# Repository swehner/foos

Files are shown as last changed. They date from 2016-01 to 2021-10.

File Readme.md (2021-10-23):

# Foosball slow motion instant replay

Ever wanted to relive your best foosball shots? Now you can with this project!
Featuring:
 * Automatic goal detection & score-keeping
 * Automatic instant replay (2x slow motion) of the last goal
 * Upload replays to Youtube
 * HipChat integration to send Youtube URLs and report game progress
 * Integration with a league system

See a video of it in action:

Instant replay video (https://www.youtube.com/watch?v=BXMhitiaXEE)

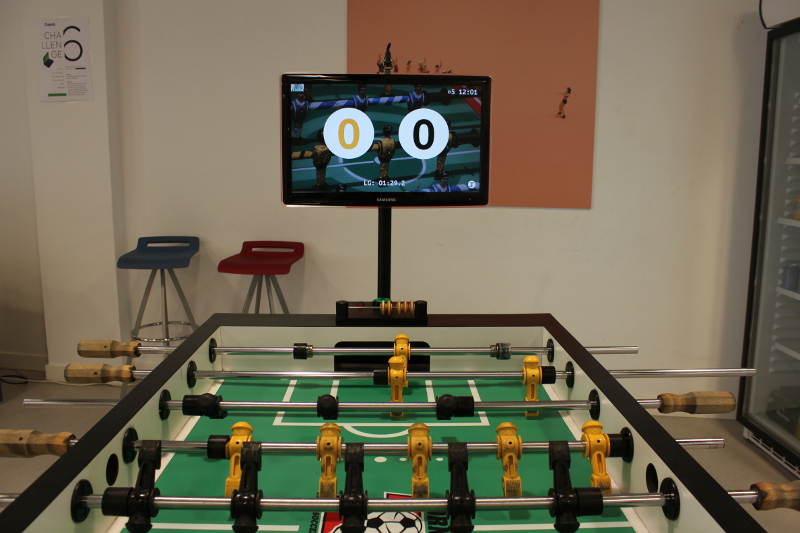
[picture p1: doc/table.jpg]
table


To build it you'll need
 * A foosball table ;)
 * A TV
 * A Raspberry Pi (2 or 3) to run the UI - **Note - the Raspberry Pi4 is not supported**
 * The Raspberry Pi camera module to record video
 * Some electronic components for the goal detection (and maybe an Arduino)

You can find more info on how to build its components in the [doc folder](doc/HWSetup.md)

Take a closer look at the UI and the different game modes in the [ui folder](doc/ui/ui.md)

## Installation

To install it on a RaspberryPi please follow the [installation guide](doc/Installation.md)

## Running on a normal PC

When running in X11 it's often useful to change the window size changing the scaling factor (-s 3 runs at 1/3 of the size)
```
python3 foos.py -s 3
```

If you want to use a keyboard on the Raspberry PI you can enable the io_evdev_keyboard plugin.
This will read directly from the evdev input device (make sure pi user is in the input group and has access to /dev/input/*)
Remember this will only work on physical keyboards attached to the PI - not if you're pressing keys in a ssh session!

Keys in X11 and Raspberry PI:
 * Increment goal counter: `q, KP7, e, KP9`
 * Decrement goal counter: `z, KP1, c, KP3`
 * Ok: `s, KP5`
 * Simulate goal: `a, KP4, d, KP6`
 * Exit: `.`

## Troubleshooting

Please check the [Troubleshooting](doc/Troubleshooting.md) section for some common issues.

## Acknowledgments

Team:
 * Jesús Bravo
 * Daniel Pañeda
 * Stefan Wehner

Big thanks to:
 * [Tuenti](http://www.tuenti.com), where this project started as a HackMeUp
 * Laura Andina for the UI design
 * [Adam Bartha](https://github.com/bartha-adam) for the Pi-only version
 * [Steve Brockman](https://github.com/sbrockman) for the Arduino micro version

Made with Pi3d

Pi3d logo (https://pi3d.github.io/)

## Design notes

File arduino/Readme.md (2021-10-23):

# Arduino Options

The [arduino](.) folder orgranizes the arduino designs into directories based on different Model/Configurations for supported Arduinos.  

The table below list the directories with their corresponding arduino model sketches.

Directory | Model | Description | Diagram |
| --- | ----------- | --------------------------- | ---- |
| foos_arduino | Nano | Original IR/NPN Design utilizing diagram | [schematic](../doc/schematics/foos_arduino_schem.png) |
| foos_arduino_micro | Micro | Original IR/NPN Design using a Micro instead of a Nano | [schematic](../doc/schematics/foos_arduino_micro_schem.png) |
| foos_arduino_micro_bb | Micro | Design utilizing Adafruit's Break Beam sensor | [schematic](../doc/schematics/micro_breakbeam_schem.png) |

Utilizing the [Adafruit breakbeam sensor](https://www.adafruit.com/product/2167), the use of the D9 (pwm) pin and NPN are eliminated.  Additionally, the D2/D3 pins have been freed up, incase we add support for an lcd1602/I2C, or lcd2004/I2C display.

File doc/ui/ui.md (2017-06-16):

# UI

Here's a quick look at the UI and the different game modes.

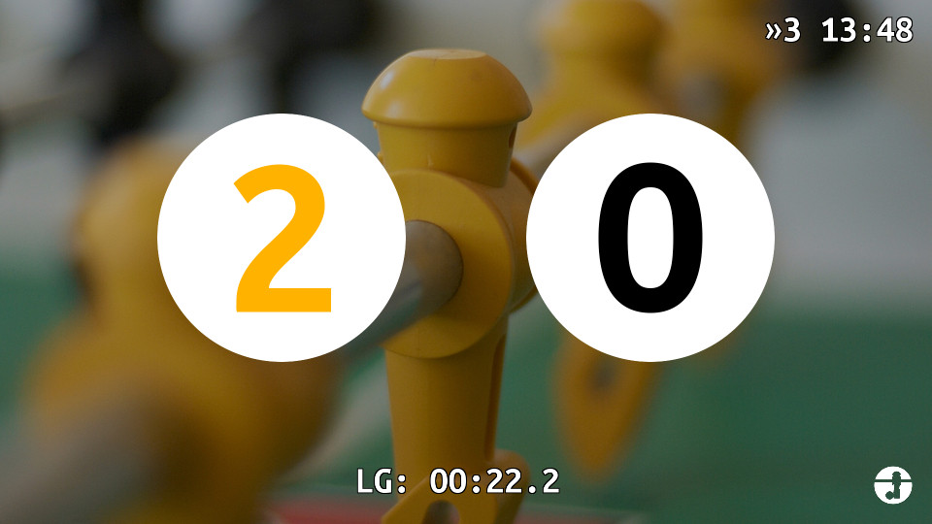
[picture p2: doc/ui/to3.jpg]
to3


## Basic game mode

In the basic game mode, the UI shows the scroe for both teams in the center, the current time in the upper right corner and the time elapsed since the last goal at the bottom.
The game can either be limited to a number of goals, which when reached displays the winning team and then resets to 0, or free, where counters simply roll over at 10.

## Menu

To change the game mode you can call up the menu (pressing the increment and decrement keys for a team at the same time, Q-Z or E-C on the keyboard)

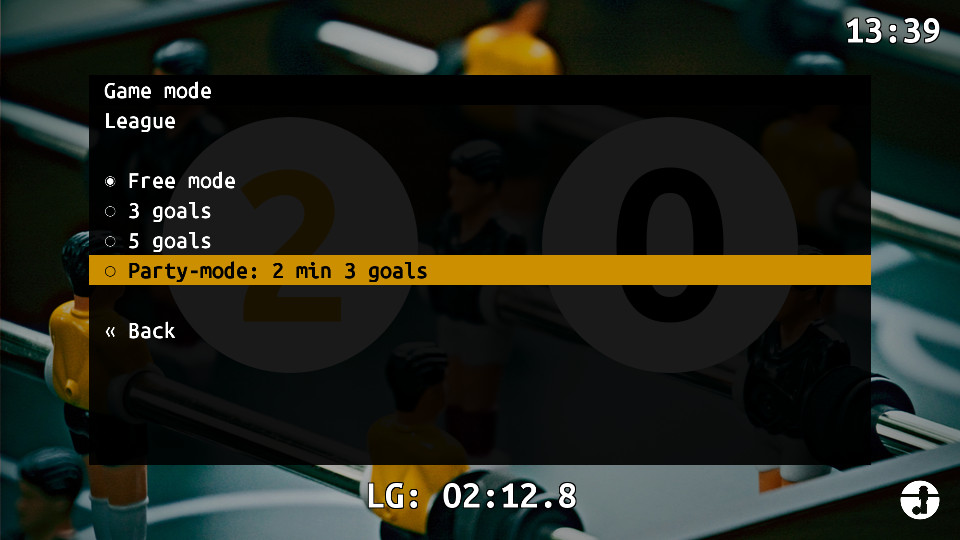
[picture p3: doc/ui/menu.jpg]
menu


Use the increment/decrement button to navigate and the replay button (S on the keyboard) to choose that menu item.

## Party mode

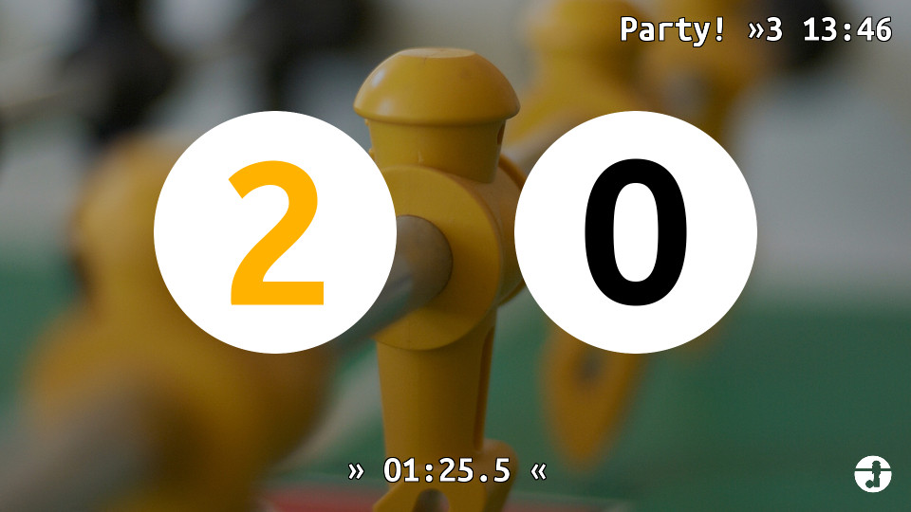
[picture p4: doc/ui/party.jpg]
party


The party mode is a game with a time limit - you can configure the winning score and the timeout in the configuration.
Party mode is indicated in the top right corner, when enabled.
The time since last goal indicator in the bottom is replaced by a countdown.
If a team wins before the time runs out, the game ends immediately. If the time runs out before, the leading time is declared winner, if no team is leading the game enters a sudden death round and the next score decides the game.
This mode is especially useful when a lot of players are playing to keep matches down to a shorter time allowing for more rotation.

## League mode

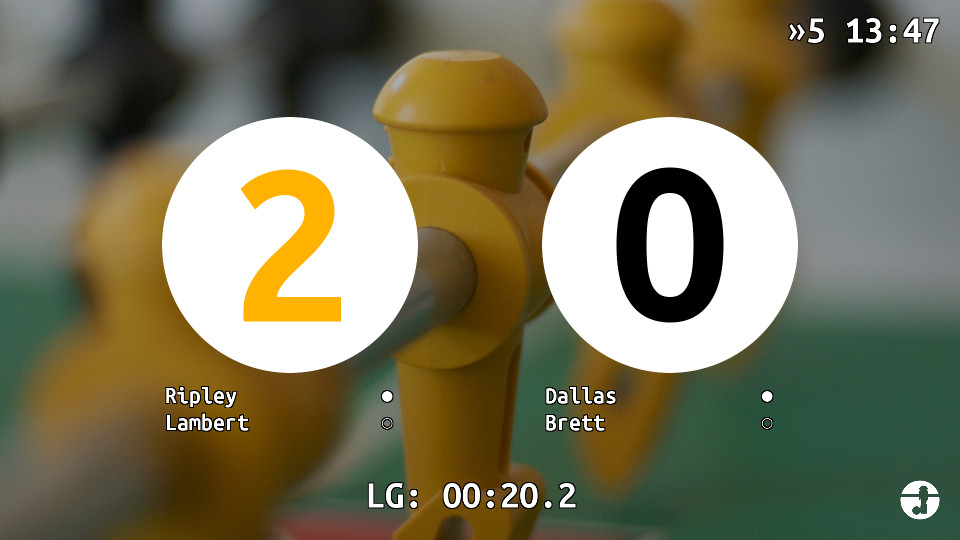
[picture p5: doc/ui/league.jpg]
league


The foosball game is integrated with a league system (https://github.com/netsuso/foos-tournament), it supports several leagues at the same time. Matches are assigned to groups of four people and will show up in the game menu.
Choose the game to play from the menu and you will start an official game. Each one consists of three matches with the players rotating so that all combination of pairs are played.
Team assignments are shown when a league game is started by showing the names of each player under the corresponding team's score counter.
After each match, a score counter is added to the player names showing how many matches the player has won/lost, and the player positions are changed.
As soon as the game ends, the results are sent to the league server, but before that official games can be aborted at any time from the menu.

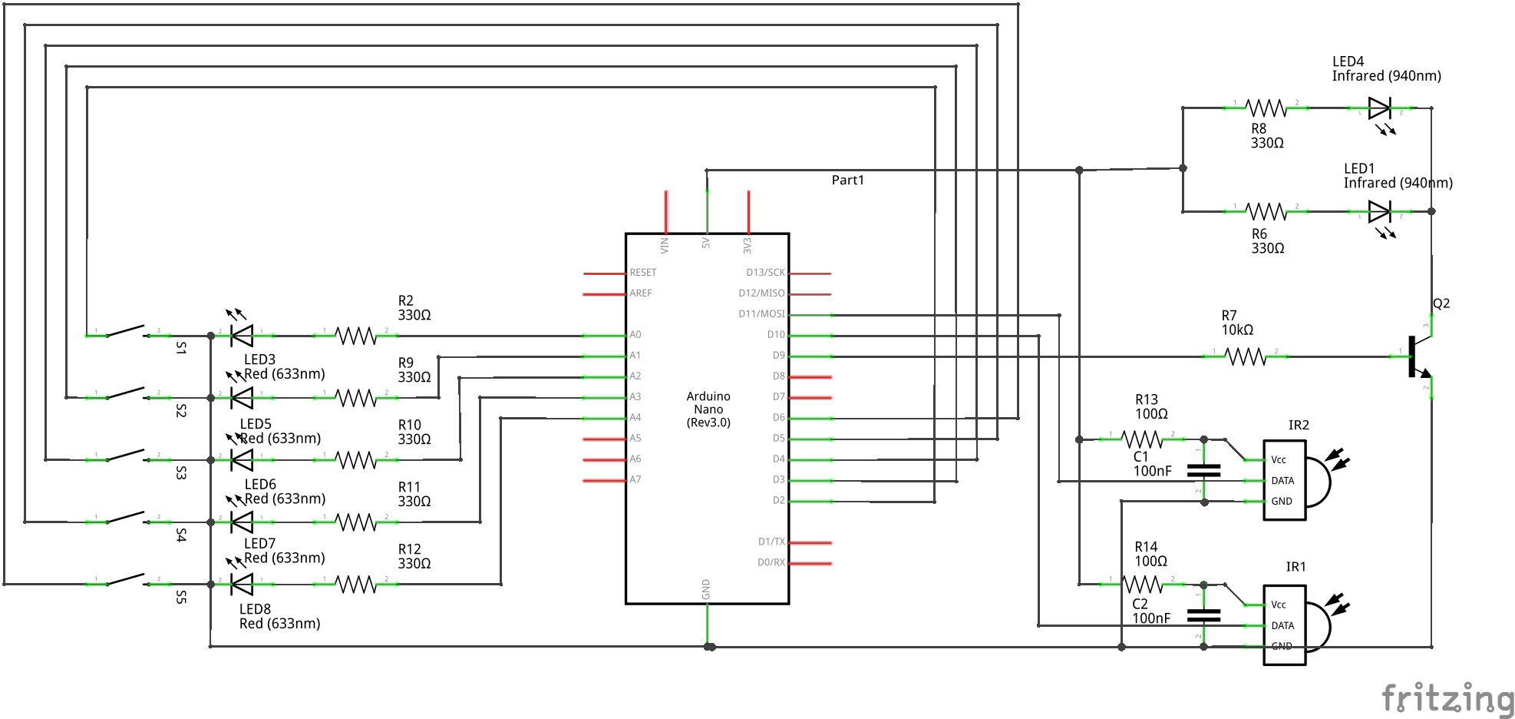
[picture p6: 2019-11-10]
doc/schematics/foos_arduino_schem.png

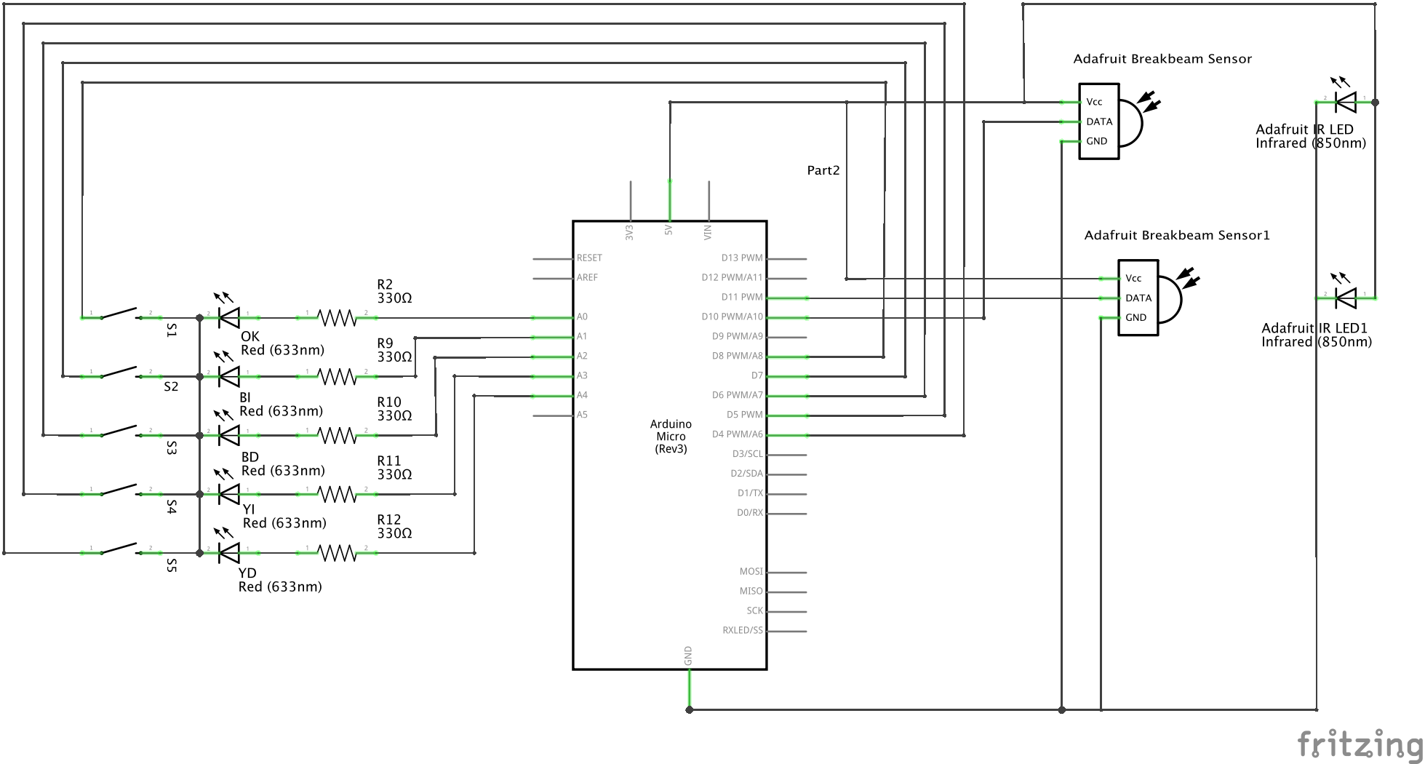
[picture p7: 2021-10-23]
doc/schematics/micro_breakbeam_schem.png

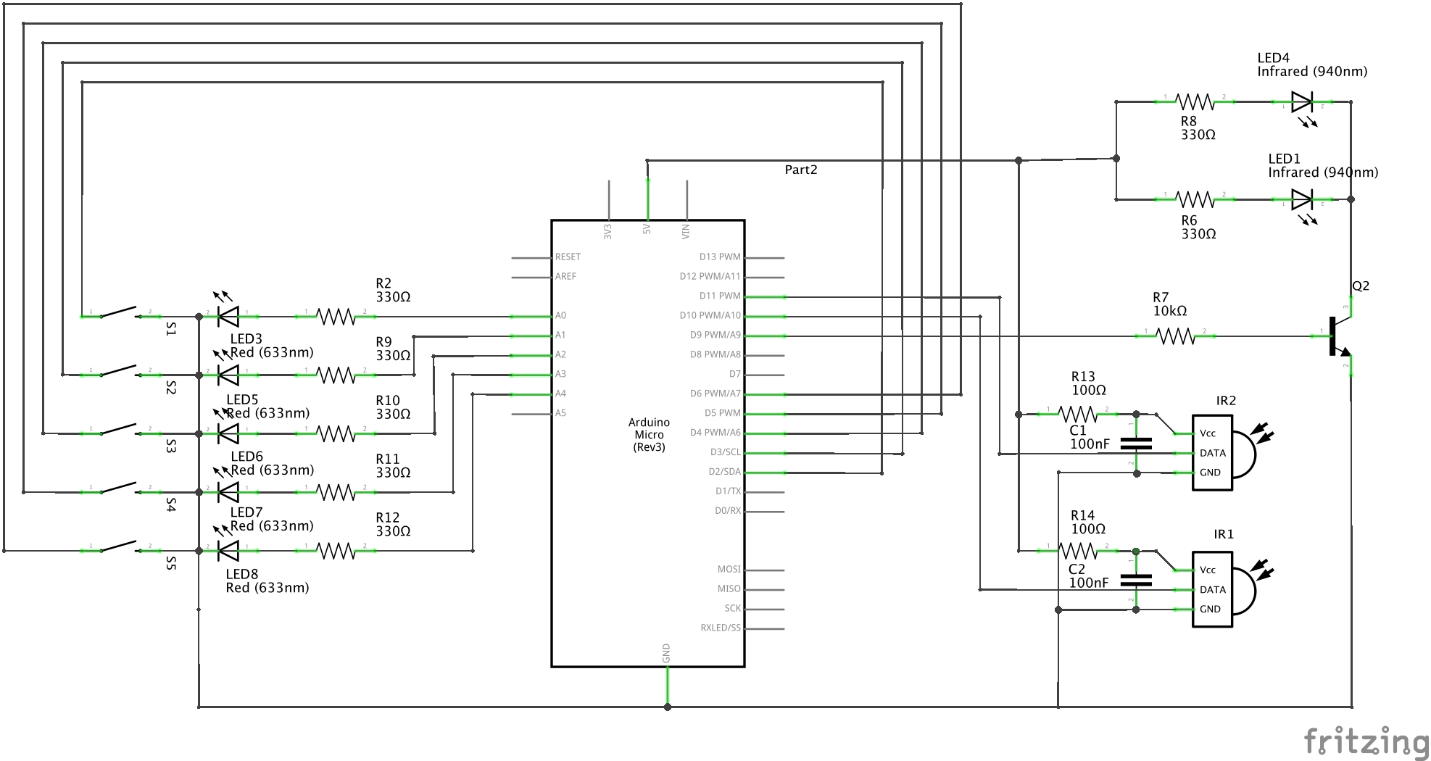
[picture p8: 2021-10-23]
doc/schematics/foos_arduino_micro_schem.png

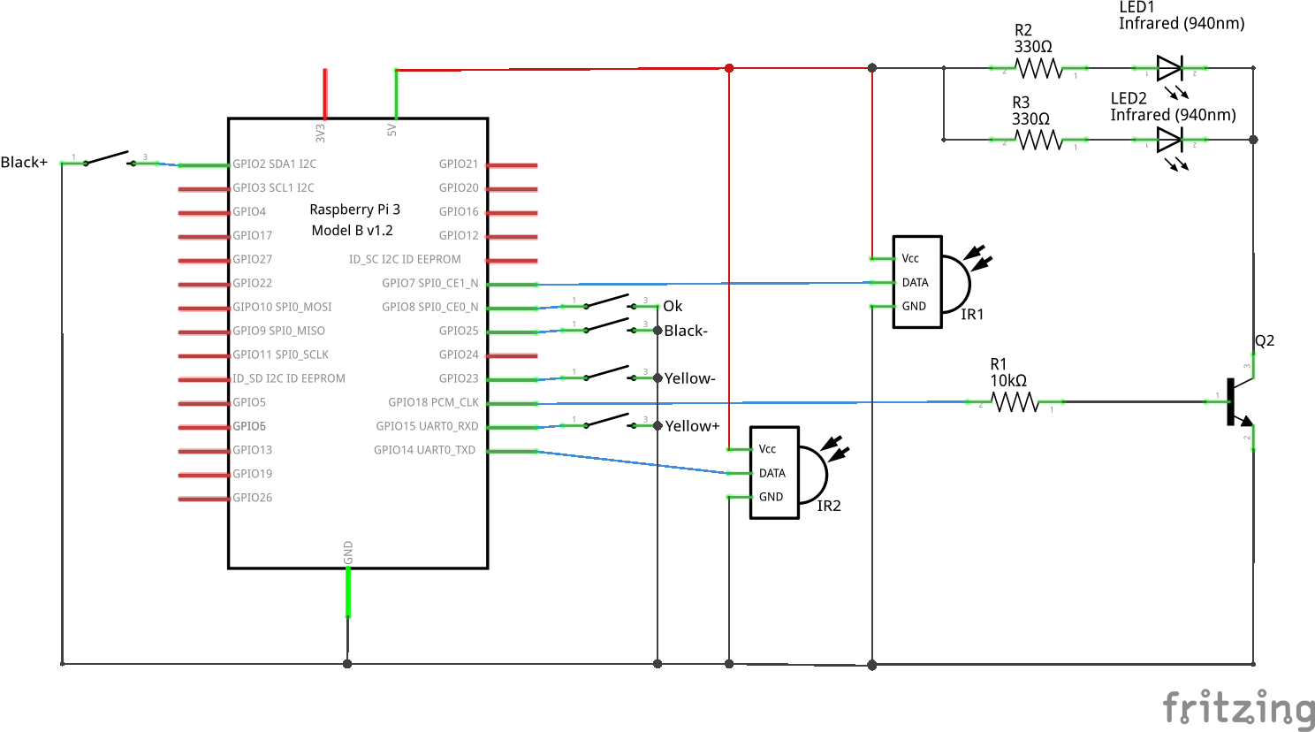
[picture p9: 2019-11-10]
doc/schematics/foos_RPi_only_schema.png

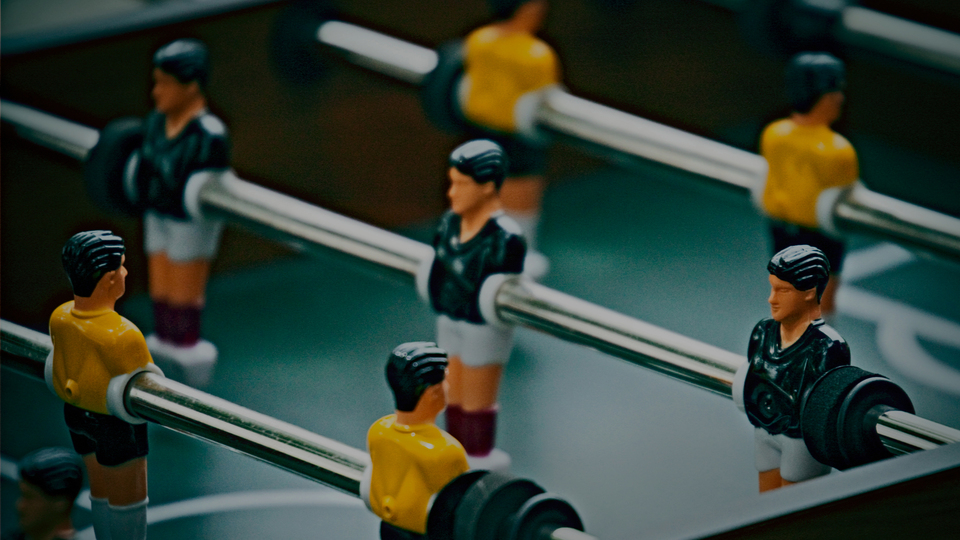
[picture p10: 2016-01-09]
img/bg/3925089065_cf3d9ea0ec_o.jpg

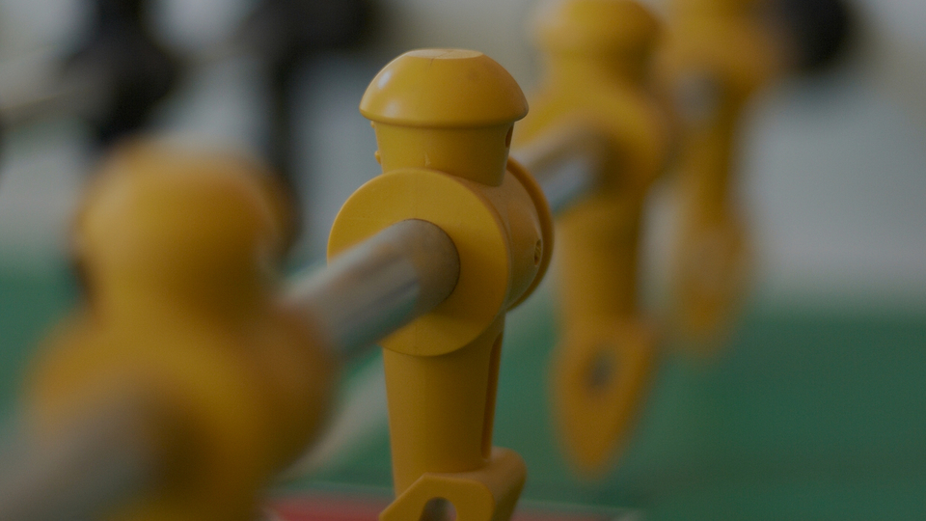
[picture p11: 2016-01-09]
img/bg/cc4.jpg

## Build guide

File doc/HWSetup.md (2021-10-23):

# Hardware Setup

These are the following hardware elements needed for the replay setup:
 * Raspberry Pi
 * Raspberry Pi camera module
 * Optional: Arduino (Nano) w/ push buttons and IR barrier
 * TV

table

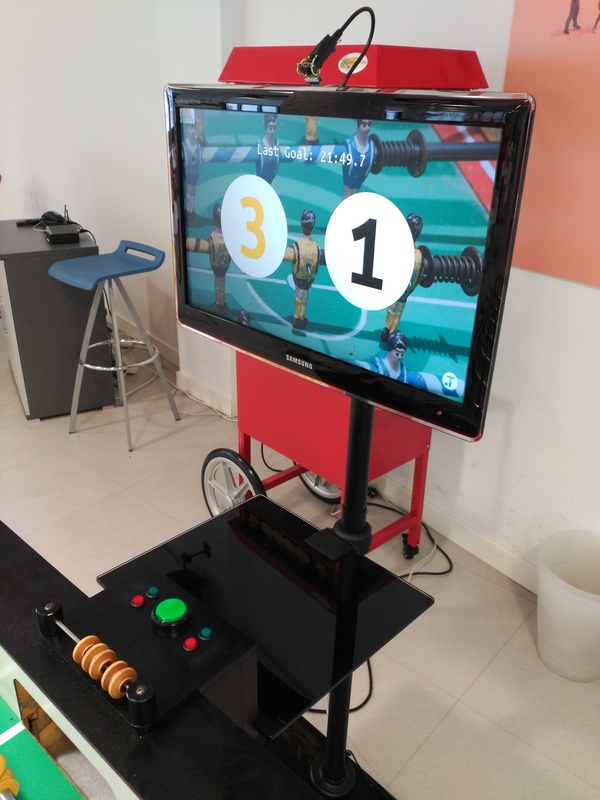
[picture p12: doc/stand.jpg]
stand


## Goal detection

We've chosen an IR barrier for the goal detection - using a regular IR LED together with the [TSSP58038](http://www.vishay.com/docs/82479/tssp58038.pdf) receiver module.
It is installed under the board, in the ball guide where the balls roll to the pick-up slot. We drilled holes on each side of the ramp and install the emitter on one side and the reciever on the other.
Due to the table's construction it's possible for balls coming in the black goal to run all the way up towards the yellow goal and actually going through the IR barrier. To avoid this there's a minimum time between goals that the GUI checks for.

IR barrier mounted undear each goal

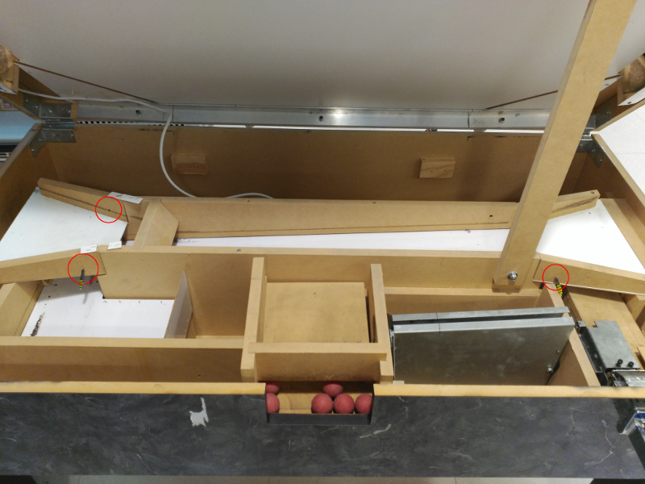
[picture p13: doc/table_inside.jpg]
Table inside overview


IR emitting LED

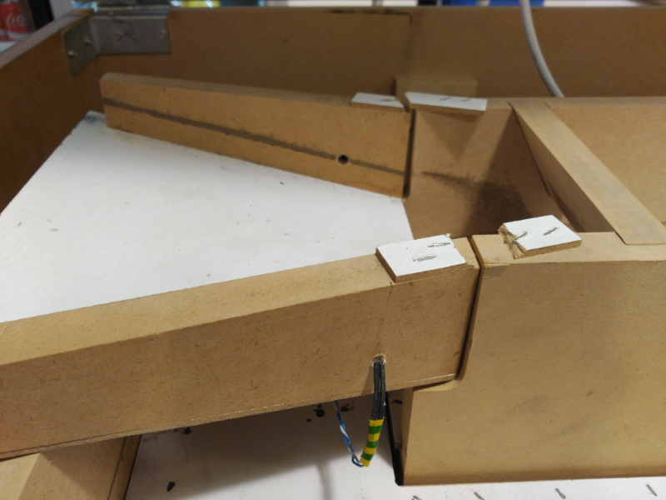
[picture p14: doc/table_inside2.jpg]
Table inside closer


IR Receiver mounted to a small piede of wood behind the hole

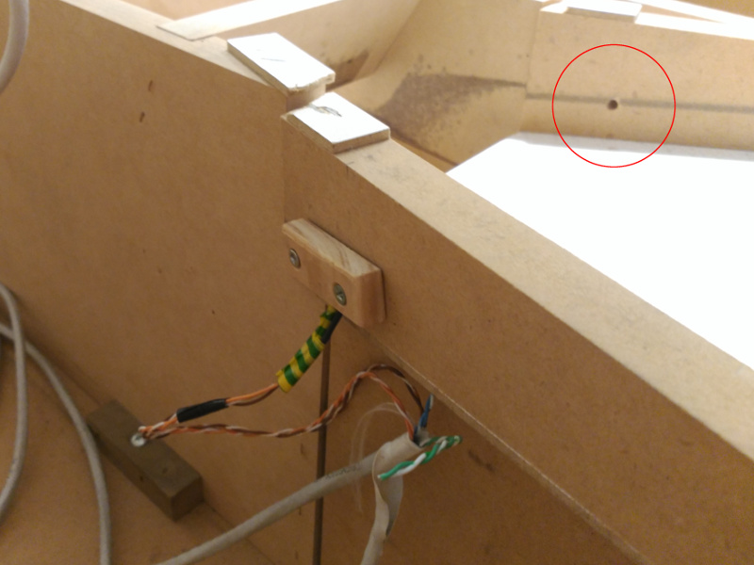
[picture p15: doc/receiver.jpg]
Receiver


## User interaction

We've included 5 push buttons so that the players can interact with the UI, to perform the following actions:
 * Increase/Decrease score for each team
 * Reset score
 * Request replay manually
 * Upload last replay to Youtube

We've tried to keep the modifications of the table to a minimum so the button box is fixed to the table using the screws of the yellow score posts.

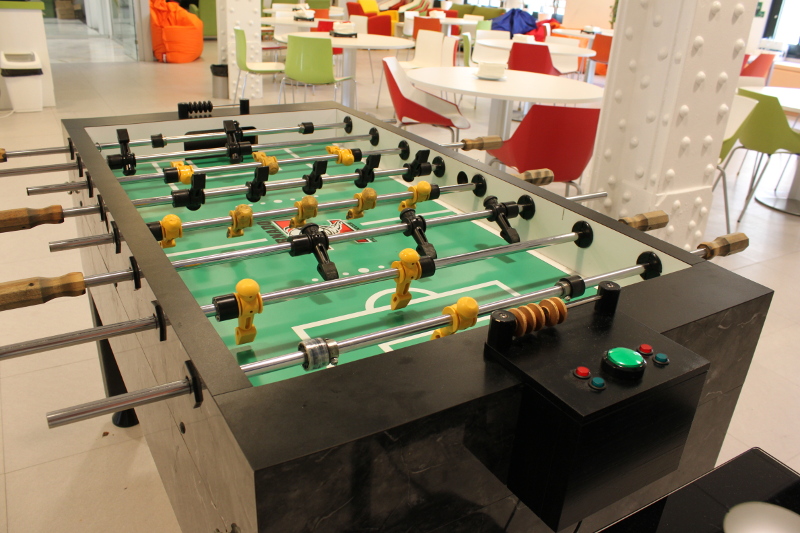
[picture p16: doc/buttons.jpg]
buttons


## Raspberry Pi

The Raspberry Pi runs:
 * GUI with TV output
 * Camera recording for replays
 * Powering Arduino and communicating with it over the serial interface

In our setup the TV is mounted on a TV trolley that is standing right beside the table. The Raspberry Pi is taped to its back with the camera sticking out over the top.
It only needs the power cable and a network cable and a USB cable to the Arduino inside the button box.

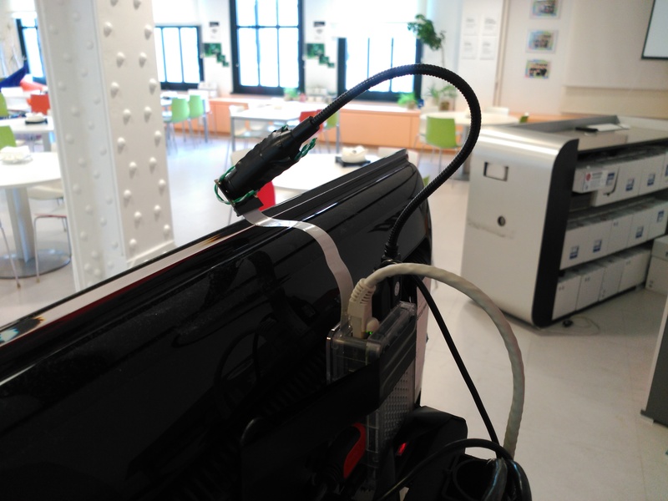
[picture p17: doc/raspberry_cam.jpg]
Raspberry Pi and Camera


## Replay

The video is recorded using raspivid at 49 fps with a fixed number of segments. When a goal occurs the replay of the last few seconds is generated simply concatenating the most recent chunks.
It is then simply replayed on a layer under the UI with a transparent background, so that the current score can be drawn on top.

## Motion detection

The motion detection is done using the motion vectors that raspivid can output to a separate file for each video chunk.
These files are read in and each frame we chck if there are enough motion vectors big enough to consider it movement.
To avoid false positives due to camera vibration we require a number of contiguous frames with movement.
All config related to motion detection depends a lot on the parameters of the camera (resolution, chunk size, etc...) and might not work correctly if the config changes.
You can find more info here: https://www.raspberrypi.org/blog/vectors-from-coarse-motion-estimation/

## Arduino

The arduino takes care of getting input from the push buttons, and detecting when a goal is scored (IR Barrier) and sends these events over the serial interface.
It also reads from the serial interface to turn the LEDs on the push buttons on off.
In our setup the arduino is inside a box with the push buttons, from there we run a multiwired cable (it's actually a cat-5 ethernet cable) inside of the table to run the IR barrier under each of the goals.
It mainly debounces all input from the buttons and the IR barriers and sends easy to read events over the serial interface.
From the bow we needed to run a cable inside of the table for the goal detecting IR barriers - here we just drilled a small hole right behind the goal.

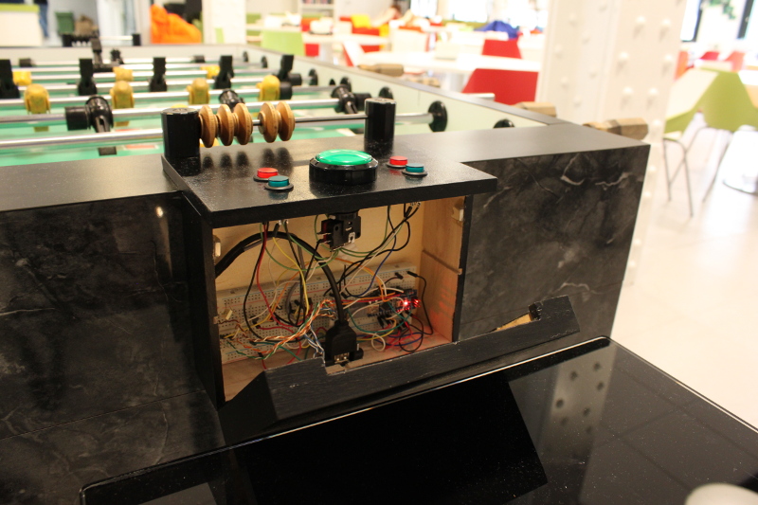
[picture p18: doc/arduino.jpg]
arduino


A 38kHz singal is required for the emitter of the IR barrier, so this signal is generated using timer1 on pin D9. We've included a transistor so the LEDs are not directly driven from the Arduino output pin.
The IR receivers are connected to Pin D2 and D3 and interrupts are attached to these pins to detect goals. The pushbuttons are connected to the digital pins following D3, and are read at a fixed interval to debounce the switches.
The button LEDS are connected to the analog pins.

### Arduino Configurations
The project now supports **three** options on **two** different models of Arduinos (Nano and Micro.)  Click to review the full list of [Models and Schematics](../arduino/Readme.md).

## Setup without an Arduino

You can also run the whole setup without an Arduino and use the RaspberryPI to generate the 38Khz signal for the IR Leds, and read the IR receivers/buttons directly from the RPIs GPIO.

You only have to connect everything directly to the RaspberryPi GPIO and enable the io_raspberry plugin (see config.py.sample for config options).
Verify the pin numbers in the config, and you're good to go!

Thanks to Adam Bartha for this!

Click here to view the schematic for the [Raspberry PI](schematics/foos_RPi_only_schema.png).

## BOM

 * [Raspberry Pi2](https://www.raspberrypi.org/products/raspberry-pi-2-model-b/)
 * [RPi camera module](https://www.raspberrypi.org/products/camera-module/)
 * Something to hold up the camera - we ended up using a flexible USB webcam similar to: http://www.goodluckbuy.com/images/detailed_images/sku_65592_2.jpg)
 * [Arduino Nano](https://www.arduino.cc/en/Main/ArduinoBoardNano)
 * 2x IR Led (e.g. Vishay TSHF6410)
 * 2x IR receiver Vishay TSSP58038
 * Push buttons (2x http://www.dx.com/p/non-locking-round-push-button-switches-black-red-2-pcs-366644 and http://www.dx.com/p/diy-push-button-switch-black-green-2-pcs-151988)
 * Breadboard
 * 7x 330 Ohm resistors
 * 1x 10k Ohm resistors
 * 2x 100 Ohm resistors (optional)
 * 2x 100nF Capacitors (optional)
 * NPN transistor (e.g. BC548, 2N2222 or similar)
 * Box for buttons

## Setup Youtube upload

To set up Youtube upload, first you need to create OAuth2 credentials for your account.
Please follow this guide: https://support.google.com/cloud/answer/6158849 and create credentials for application type other.
Download the client_secrets.json file and place it into the foos root folder.

Restart foos.py and upload the lates replay (long-press on 's', central button). Check the console output, it should show something like:

```
Go to the following link in your browser:

    https://accounts.google.com/o/oauth2/auth?...

Enter verification code:
```

Go to that URL on a browser, get and enter the verification code.

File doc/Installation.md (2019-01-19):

# Installation

## Install Raspbian on SD

Install Raspbian image from here:

https://www.raspberrypi.org/documentation/installation/installing-images/README.md

I usually use the lite image because it comes without the desktop.

I find it a lot easier to connect the raspberry pi to the network and access it via ssh. If you want to do so you need to enable it.

https://www.raspberrypi.org/documentation/remote-access/ssh/

## Install foos and dependencies

Install git:
```
pi@raspberrypi:~ $ sudo apt-get update
...
pi@raspberrypi:~ $ sudo apt-get install git
...
```

Clone the repo:
```
pi@raspberrypi:~ $ git clone http://www.github.com/swehner/foos
Cloning into 'foos'...
remote: Enumerating objects: 2331, done.
remote: Total 2331 (delta 0), reused 0 (delta 0), pack-reused 2331
Receiving objects: 100% (2331/2331), 28.52 MiB | 1.26 MiB/s, done.
Resolving deltas: 100% (1463/1463), done.
```

Copy the config file:

```
pi@raspberrypi:~/foos $ cp config.py.sample config.py
```

Run the check.sh program to see what's missing

```
pi@raspberrypi:~/foos $ ./check 
Checking environment...

* Binary deps:
[ERR] play (needed for sound) not found!
[ERR] avconv (needed for upload) not found!
[ERR] cec-client (needed for standby) not found!
[ OK] python3 (needed for foos) found
[ERR] pip3 (needed for foos) not found!
====> Try: sudo apt-get install python3-pip cec-utils libav-tools sox 

* RaspberryPi specific deps:
[ OK] /opt/vc/bin/raspivid (needed for camera)
[ERR] video/player/player (needed for replay) not found
====> Try: pushd video/player; make && popd 

* Replay path:
[ OK] /dev/shm/replay is on a tmpfs
[ OK] /dev/shm/replay is writable

* GPU settings:
[ERR] GPU memory too low: 64 - we recommend 192 or more
====> Try: sudo raspi-config # and raise the split memory setting 

* evdev input:
[ OK] /dev/input seems readable io_evdev_keyboard should work

* Python deps
[   ] Can't check python3 deps for the moment - if you have issues:
====> Try: pip3 install -r requirements.txt 

* Test Replays - press Y to test N to skip
Running camera...
mmal: mmal_vc_component_create: failed to create component 'vc.ril.camera' (1:ENOMEM)
mmal: mmal_component_create_core: could not create component 'vc.ril.camera' (1)
mmal: Failed to create camera component
mmal: main: Failed to create camera component
mmal: Camera is not enabled in this build. Try running "sudo raspi-config" and ensure that "camera" has been enabled

ls: cannot access '/dev/shm/replay/fragments/out*.h264': No such file or directory
video/replay.sh: 12: video/replay.sh: video/player/player: not found

* Finished!
```

This program should guide you with all the required steps. Please follow its output rather than this guide, as it should be more up-to-date.

* Install dependencies:

```
sudo apt-get install python3-pip cec-utils libav-tools sox libatlas-base-dev libtiff5
```

* Compile deps:
```
pi@raspberrypi:~/foos $ pushd /opt/vc/src/hello_pi; ./rebuild.sh; popd
```

* Compile the player:
```
pi@raspberrypi:~/foos $ pushd video/player; make && popd
```

* Check GPU memory settings & enable camera:

```
pi@raspberrypi:~/foos $ sudo raspi-config
```

* Python deps:

```
pip3 install -r requirements.txt
```

* Reboot and run check again to see if everything is working as expected :D

### Configure your foos installation

Foos uses a set of plugins to configure what features are enabled.
Review the config.py file you've copied before to enable different features.
You should only have to uncomment the corresponding lines in the config file.

### Start foos on boot

To start foos on boot you can add it to /etc/rc.local

```
$ sudo vi /etc/rc.local
```

Add

```
sudo -u pi /home/pi/foos/foos.sh &
``` 

before

```
exit 0
```

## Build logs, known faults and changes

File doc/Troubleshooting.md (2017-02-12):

# Troubleshooting

### The rainbow box appears in the upper right corner

This is Raspberry PI under-power warning - it means that your power supply is not delivering 5V. Try a supply with a higher power rating. See here for recommendations:
https://www.raspberrypi.org/help/faqs/#power

### When the replay is supposed to show nothing appears on screen and the score counters don't go back to their original position

This is most likely because you don't have enough RAM assigned to your GPU. See next question.

### Some UI elements are not drawn correctly and show as gray/black boxes instead

This is most likely because you don't have enoguh RAM assigned to your GPU. We recommend 256MB. Use raspi-config to change it.

### The player blacks out after a few seconds or video shows tearing

This could be related to issues with dispmanx compositing:
Check if you have enabled drawing the background as a dispmanx layer in the config:
```
draw_bg_with_dispmanx = True
```

You can disable it in config (it is False by default) - if you still want to do it as a dispmanx layer there are several options to fixing this problem.
A solution to this problem is reducing the dispmanx layers - you have several options for that:

You can turn off the framebuffer doing the following before launching foos.py. This is done automatically when starting it from the console, but if you've started if through ssh you need root permissions to do this:
```
sudo sh -c "setterm -term linux -blank force >/dev/tty0 </dev/tty0"
```
Or you can use tvservice to disable and reenable HDMI output:

```
tvservice -o; tvservice -p
```

To get the console back you can run:
```
sudo sh -c "setterm -term linux -blank poke >/dev/tty0 </dev/tty0"
```

Another option is to disable the camera preview in config.py:
```
camera_preview="-n"
```

If none of these work you can try enabling offline compositing in dispmanx in /boot/config.txt (reboot required!):
```
dispmanx_offline=1
```

### Replay video doesn't cover full screen

Probably your screen doesn't have a 16/9 aspect ratio.
You can configure the recording size in config.py. This is the config I use for a 16/10 monitor:

```
video_size=(1152, 720)
camera_preview="-p 0,0,115,72"
```

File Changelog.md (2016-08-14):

# Changelog

## v20160814

* Introduced new config format with overrides (instead of copying a full set of config values to config.py simply override values deviating from the base - see new config.pysample)
* Added evdev keyboard
* Add check script
* Set default video size to 1280x720
* Move default replay and log paths to /dev/shm

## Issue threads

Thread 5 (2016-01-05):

Display stuck in overlay mode

swehner, 2016-01-05:
The UI got stuck at some point in overlay mode. All events seemed to be working fine it simply didn't ever go out of overlay mode.

hello_video seems to be stuck and doesn't finish - that way the ui doesn't receive the replay_end event.
Even killing all instances doesn't seem to make them work again - Maybe something isn't cleaning up correctly... We can try with omxplayer again...

swehner, 2016-01-07:
Could be related to this error showing up in dmesg:

```
[ 6598.651071] ------------[ cut here ]------------
[ 6598.655910] WARNING: CPU: 2 PID: 19848 at drivers/misc/vc04_services/interface/vchiq_arm/vchiq_arm.c:2484 vchiq_release_internal+0xac/0x244()
[ 6598.668882] Modules linked in: ch341 usbserial bcm2835_gpiomem uio_pdrv_genirq uio sch_fq_codel snd_bcm2835 snd_pcm snd_timer snd bcm2708_rng rng_core ip_tables x_tables ipv6
[ 6598.685069] CPU: 2 PID: 19848 Comm: HTV Notify Not tainted 4.1.10-2-ARCH #1
[ 6598.692210] Hardware name: BCM2709
[ 6598.695782] [<80015dd4>] (unwind_backtrace) from [<80012d58>] (show_stack+0x10/0x14)
[ 6598.703698] [<80012d58>] (show_stack) from [<80780f6c>] (dump_stack+0x84/0xc4)
[ 6598.711112] [<80780f6c>] (dump_stack) from [<8002f9bc>] (warn_slowpath_common+0x84/0xb4)
[ 6598.719419] [<8002f9bc>] (warn_slowpath_common) from [<8002fa88>] (warn_slowpath_null+0x1c/0x24)
[ 6598.728419] [<8002fa88>] (warn_slowpath_null) from [<80558408>] (vchiq_release_internal+0xac/0x244)
[ 6598.737700] [<80558408>] (vchiq_release_internal) from [<80559034>] (vchiq_ioctl+0x7c8/0x1750)
[ 6598.746519] [<80559034>] (vchiq_ioctl) from [<8015ee58>] (do_vfs_ioctl+0x3e8/0x608)
[ 6598.754336] [<8015ee58>] (do_vfs_ioctl) from [<8015f0ac>] (SyS_ioctl+0x34/0x5c)
[ 6598.761832] [<8015f0ac>] (SyS_ioctl) from [<8000f360>] (ret_fast_syscall+0x0/0x3c)
[ 6598.769577] ---[ end trace d2157e5f0135c220 ]---
[ 6598.774328] vchiq: vchiq_ioctl: cmd VCHIQ_IOC_RELEASE_SERVICE returned error -1 for service TVNT:19845
```

This happened at the second replay after the TV was turned back on - maybe there's some issue with this?

swehner, 2016-01-14:
Was actually a GPU memory issue. Fixed now with the smaller BGs.

Closed 2016-01-14.

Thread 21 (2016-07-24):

Screen Resolution Config

danpillay87, 2016-07-24:
Hi guys - awesome work here - whats the bes way to debug on my install python3 foos.py is just hitting me with a whitescreen after Run GUI makes it to the console.

Is there any additional config I should be doing? Not sure if I needed to set up the league system in advance tbh as I havn't seen the GUI.

any help appreciated :) happy to do a full noob write up once I have this nailed...

swehner, 2016-07-24:
Hi,

What platform are you trying to run it on and with what version of Pi3d?
Can you also please post the whole output on the console? Maybe we can find some hints there.
If you're running on the RaspberryPi, have you checked this out: https://pi3d.github.io/html/FAQ.html#white-screen

If it is related to memory issues on the RaspberryPi you might want to check the output of vcdgb reloc  while it is running, to see how much memory is free/being used.
Let me know if you have some more information to go on and we'll see if we can help somehow!
Thanks!

ErnieTheTech, 2016-07-28:
Hey Dan, I was having the white screen issue on my TV at work and one at my home but my 2nd tv at home loaded full screen.
I think has to do with default resolution. You should be able to get it running slightly on any tv doing -s 3 which will display in a tiny portion of the screen.
Is there a default resolution in a config somewhere?
Unfortunately once the GUI loads, I can't do anything with a keyboard.
On an unrelated note, I was getting a syntax error running a copy of the sample config.py file.
It points out maxBytes in the code and the GUI won't load unless I comment the line out and save the config file.
Thanks for all your help.

dpaneda, 2016-07-28:
Fixed syntax error in the sample config at 504c3b5d4d26ebe8ef0cc351814b0273349b776c
I'm not sure about the default resolution, @swehner is our gui expert :D.
About the keyboard problem, did you try the control keys specified on the Readme?

swehner, 2016-07-28:
Thanks for fixing this, @dpaneda :)
So - regarding the resolution: by default it'll try to use the whole display and scale the camera accordingly.
Like @ErnieTheTech said, if you specify a scaling factor on the command line the window size will be forced to <1920/sf>x<1080/sf>.

I think the keyboard commands specified in the README work only when running in X11.
So if you run it on the Raspberry Pi directly from the command line this doesn't work I think.
I'll double check it - but the io_keyboard plugin is specific to X11 and is only loaded if Pi3D detects it's running under X.
I'll take a look to see if we can get this running also when running without X.

If you can ssh into the RaspberryPi you can use the scripts in debug to trigger events https://github.com/swehner/foos/tree/master/debug - so this can simulate inputs from the serial port.

danpillay87, 2016-07-28:
thanks guys - I tried both of these - I just removed any raspbian related GUI stuff from the pi which seems to have resolve my whitescreen issue - have also managed to resize the foos gui on my TV so I'm getting ish better results but yeah @ErnieTheTech the -s3 command would be pretty helpful.

ErnieTheTech, 2016-07-28:
Thanks @dpaneda , that worked great.
@swehner , is there a way I can set the exact resolution? Its running OK on a monitor and one TV but its not perfect (black line where the time is). I would like to be able to set the resolution if possible.
I will check out the keyboard later today.

ErnieTheTech, 2016-07-28:
@danpillay87 , what did you remove? What did you do to resize the GUI?

swehner, 2016-07-28:
@ErnieTheTech Nope - at the moment it's not possible to set the exact resolution without changing the code. If you want to try you can try to play around with the size in  https://github.com/swehner/foos/blob/master/foos/ui/ui.py#L263
What's the resolution/aspect ratio of your TV you're trying to set up? Can you also please tell me what python3 foos.py (without the -s argument) prints when running?
It will print the display size detected by pi3d

So to explain a bit more: the GUI is layed for an aspect ratio of 16:9 (all positions are hardcoded on a 1920x1080 screen) and scaled if the window is to be drawn with a different size.
By default it will try to use the full screen size - if your TV has a different aspect ratio it's very likely you'll see black bars on top or bottom - might that be your issue?

ErnieTheTech, 2016-07-28:
So on a standard monitor, SSH from another computer without -s it sets the size to 1366x768@25. You can see the black bars.
When -s 3 it sets to 640x360@25 and everything seems to display correct, only smaller.
Pictures below:

https://1drv.ms/i/s!Ajbtyf8_31eygoVX3WK3hkW18B_oDg

https://1drv.ms/i/s!Ajbtyf8_31eygoVYtlk9ck01QB0lpw

swehner, 2016-07-28:
Thanks for the screenshots! Very helpful and quite different from what I thought it was.
Because the size is ok, it's just that it's not drawing the text correctly.
I'm suspecting a GPU memory issue here - I think I had these kinds of issues when trying to load too much into the GPU memory (e.g. too many images at the same time)
Can you verify what your GPU memory setting is? And what your free memory for GPU is?

You should get the amount of free memory doing sudo vcdbg reloc - this will show all reserved blocks and also what memory is free still.
I'd recommend raising your assigned memory for the GPU (I think at least 128MB if not more) - you can use raspi-config for that.
Let me know if that changes anything!

ErnieTheTech, 2016-07-28:
@swehner, it was set to 64 so I changed it to 128 and 256. Check the image below. Seems there are now 5 black dots near the the bottom center. I rebooted so that several different images would boot up but same result.
*Please note that I dont have anything connected or configured at this time. Just the Pi and all the required installs.
Also, for the camera-can I use any compatible USB camera or must it be one connected via ribbon and board?
A big thank you for helping me out in the project. I hope you don't mind all the questions. I have a few weeks off from school and wanted to complete this before the semester.

Photo:
https://1drv.ms/i/s!Ajbtyf8_31eygoVaAIdyIoPKwl5zGw

swehner, 2016-07-28:
Awesome! The black dots are actually an on screen display for the LED buttons we have on the box.
So that is completely normal - if you use the debug script to send a goal you should actually see them flashing...
You can disable them setting onscreen_leds_enabled to False in your config.py. See here: https://github.com/swehner/foos/blob/master/config.py.sample#L1
Verify that it's written correctly and that should be enough :)

Re: the camera - nope, we don't support a USB camera - only the RaspberryPi camera.
Most USB cameras don't do more than 30fps with isn't enough for slow-motion replays and I'm not sure how well supported they are...
Right now everything's tailored to raspivid and how the video recording works there.
So generally, getting a USB camera to do the replays could be doable but it'll be a lot more work, and we're definitely not supporting it.

swehner, 2016-07-28:
BTW: If the ribbon cable length is an issue for you we can recommend this: https://www.tindie.com/products/freto/pi-camera-hdmi-cable-extension/
It's awesome!

ErnieTheTech, 2016-07-28:
Awesome, perfect! Time to order a few items. I just got my arduino in today so I will be playing with next couple of days. Hopefully I can leave yall alone for now :)

Thanks again for all the help.

swehner, 2016-07-28:
No problem - these are quite a few things we weren't aware of. I'll try to see if we can either include them somehow in the program itself (check for enough GPU memory) oor at least document them in the README.
Have fun with the Arduino :)

@danpillay87 have you checked if your problems were also related to the GPU Ram settings?

ErnieTheTech, 2016-07-29:
@swehner . So playing with the arduino is pretty simple. The kit I bought came with buttons to play with. I have been able to communicate with the Pi using simple push button scripts and works fine.
How can I play with the push button config in foos? I had to set the usb port when running button scripts so wont I need to set that in foos?

swehner, 2016-07-30:
Foos will try to open a serial connection on any of the /dev/ttyACM* or /dev/ttyUSB* ports.
See here for connection params: https://github.com/swehner/foos/blob/master/plugins/io_serial.py#L66
Our arduino setup basically writes strings for btn up/down events and goal events. You can see them both here: https://github.com/swehner/foos/blob/master/plugins/arduino.py the raspberry pi side and in the arduino code file here: https://github.com/swehner/foos/blob/master/foos_arduino/foos_arduino.ino.
Don't forget to add the io_serial in config.py pluing list. Have fun :D

ErnieTheTech, 2016-08-01:
@swehner Worked great after I added io_serial to config.
I am getting this from SSH but everything loads and seems to play fine:

Traceback (most recent call last):
  File "/home/pi/Desktop/foos/plugins/io_serial.py", line 38, in reader_thread
    line = line.decode('ascii').strip()
UnicodeDecodeError: 'ascii' codec can't decode byte 0xff in position 0: ordinal not in range(128)

**Sorry if this is simple fix but I am a Network admin and only know a little about code**

danpillay87, 2016-08-14:
hi @ErnieTheTech having a little trouble with my arduino set-up don't suppose you have anything you could share to help me on my way? The images on the readme are a bit tricky and I want to make sure I've understood the schematic and the useage of io_serial correctly.

Cheers

swehner, 2016-08-14:
For the schematic you can also check the fritzing file: https://github.com/swehner/foos/blob/master/doc/foos_arduino.fzz
Maybe that it easier to check than the images.

danpillay87, 2016-08-16:
cheers swehner - trying it just with buttons and skipping the sensors for the minute to try and isolate the prob. Don't suppose there are any forced commands I can try in debugging to check the arduino setup is okay that people know of? I'm reading it on ttyUSB001 just fine so I'm assuming it's all good but the constant short goal trigger is puzzling me :/

swehner, 2016-08-19:
I'm gonna go ahead and close this - I think the original issue was addressed and we're talking about the arduino issues in #33

Closed 2016-08-19.

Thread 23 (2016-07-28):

run_camera.py debug

danpillay87, 2016-07-28:
hallo - using the debug commands to simulate events at the moment and have tested all events successfully other than instant_replay.sh - on this I'm getting a black screen.

the picam works no issues from the command line so trying to debug that part of the set-up. I'd like to run 'sh run-camera.sh' to debug it but I'm getting the error below:

`mkdir: missing operand
Try 'mkdir --help' for more information.
stat: missing operand
Try 'stat --help' for more information.
mmal: main: Error opening output file: /fragments/out%04d.h264
No output file will be generated

Error opening output file: /fragments/mv%04d.txt
No output file will be generated
 mmal: Aborting program`

does anyone have any suggestions in regards to testing the rest of the software before I start destroying my beloved foosball table? :)

Thanks everyone!

swehner, 2016-07-28:
So, to run the camera you have to enable the corresponding plugins in config.py:
So you should enable "camera", and "replay" and disable "replay_debug".
(Basically adding the two to the plugins list in config.py and removing replay_debug)
The main program foos.py should take care of running everything and creating the necessary directories for the replay - Did you do that?
If you want to run run_camera.sh by hand you have to give it a base_path (try for example run_camera.sh /home/pi/replay) where to write capture files and replays - take a look at the script to see what it's doing.
It's not really thought to be run by hand and it's not doing any error checking :S

danpillay87, 2016-07-30:
thanks for the info - I hadn't enabled the right plugins so that was the issue - I've done that now though and I'm getting the top left visual from the picam in the GUI :+1:

Was trying to use sh instant_replay.sh to ensure the replay was working - but the  the replay seems to skip through with nothing. - I guess it's because there's nothing recorded.
[https://goo.gl/photos/jpRj2rjJe4sxQfqD9](url)

Any suggestion of how I could test the instant replay before I finally crack open the foos table?

Thanks a lot in advance,

swehner, 2016-07-30:
Ok - do verify that you have disabled the "replay_debug" plugin and the "replay" plugin is enabled.
Check if there are fragments in your the directory where foos is running.
So probably in /home/pi/foos/replay/fragments - these are the video chunks from the replay.
As soon as a goal event ocurrs (or the instant_replay request) the files foos/replay/replay_short.h264 and foos/replay/replay_long.h264.
If these are fine, check that you can play them on the pi with /opt/vc/src/hello_pi/hello_video/hello_video.bin (this is the binary we use to replay).
Do also check the console output after you quit foos - it should complain about if there's anything missing!

danpillay87, 2016-07-30:
cool - I can verify "replay" enabled and "replay_debug" is removed.

I'm in  /home/pi/foos/video/fragments rather that /home/pi/foos/replay/fragments - which I guess should be fine - but I don't have any fragments generated in here - I thought these would be generated automatically based on the motion detected but I though I might be able to fake this with the movement, then triggering a goal by ssh into the pi. - but maybe I'm wrong on that and I should just throw in some fragment there for testing and assume the fragments will be created correctly once I finish hooking up the arduino?

swehner, 2016-07-30:
No no, the camera should be generating fragments continuously - and it's running, as you've said that you can see the little window in the corner.
Sorry I forgot that the replay_path is actually configured in config.py - by default it's /home/pi/replay.
The folder you mentioned must have been created when you ran the script manually.
Check what is in there, please.
You can also verify where raspivid will write checking the paramters doing:
`ps ax | grep raspivid`
Motion detection is another thing that works on the utput that raspivid generates.
If the camera is running you should see that fragments are being written in /home/pi/relay/fragments.

danpillay87, 2016-07-30:
ah gotcha - makes more sense - I've adjusted the config file to my video location as that had /fragments/ in it anyway - I checked with grep raspivid and all looks good and when running foos.py now my fragments dir is filling but, under my /video/ dir that was created i don't have replay_long.h264  replay_short.h264 - so I guess that's still not working.

I'll try switching it all back over to /replay/ now to see if that resolves things

swehner, 2016-07-30:
Just to be clear:
The two replay videos are generated whenever a goal/replay event occurs - so in your case when you run the debug/instant_replay.sh or debug/goal_black.sh.
So check that they are generated when you run any of these scripts and then check that the player I mentioned works.
I recommend you to delete all files of your old video directory. foos mounts the dir for replays in RAM so that it doesn't fry the SD card, so to free up some RAM delete those old files.

danpillay87, 2016-07-31:
ok so I've tested the player and can confirm my hello_video works.
My replay path is now set as replay_path = '/home/pi/replay'

and my camera and replay plugins are enabled with their counterpart debug plugins disabled.
now when debugging with sh instant_replay.sh I'm getting the wipeaway that pushes score to the top right but the camera in the top left stays minimised and I have the console running behind. Where I can see that a new debugging session is running...but not much else.

Am I missing something obvious on this, I did a complete fresh install on a separate raspi so it should be fairly clean as far as setup goes.

Appreciate the help in further debugging!

swehner, 2016-07-31:
Hey @danpillay87
Sorry to hear that it's still not working.
Just FYI: The camera will always be visible in the top corner - What should happen is that the video of the replay is being played in the background.

Can you please answer the following questions:
* Do you see any errors/messages on the console where you ran python3 foos.y while toing the replay?
* How long does it take for the counter to go back to their normal size?
* Do you have /home/pi/replay/replay_short.h264 and/or /home/pi/replay/replay_long.h264?
* If yes: Can you play this file with /opt/vc/src/hello_pi/hello_video/hello_video.bin and does this show the video on the screen? Any errors/output on this program?

I think there's nothing obvious wrong - the most important would be to check any error messages to see what's wrong...

danpillay87, 2016-08-01:
@swehner appreciate the support so far.

I took a break and I've returned motivated to find the solution! in answer to your questions:

- the replay isn't showing any errors my logging shows the standard for the GUI
loading plugins ['replay', 'camera', 'score', 'game', 'io_debug', 'menu', 'control', 'league', 'event_debugger']
loaded all plugins.
Run GUI
Getting game mode None None
compiled
compiled
opened new bugging session
goal_event: {'team': 'black', 'source': 'serial'}
.... so doesn't seem to be anything there....

- the counters don't appear to return to their normal size - they just reduce, showing the console in the background, so not sure if I should be running this differently in production somehow?

- I do have both those files

- I can indeed play the files with hello_video.bin but not getting any errors.

Apologies I don't have a useful error message but any ideas welcome!

danpillay87, 2016-08-01:
on exit of foos.py - to try and debug the issue further, if I've triggered sh instant_replay.sh and then exit I'm getting the following errors:

```
traceback (most recent call last):
File "/home/pi/foos/foos/ui/ui.py", line 469 in run while self.DISPLAY.loop_running():
File "user/local/lib/python3.4/dist-packages/pi3d/Display.py", line 283 in loop_running self._loop_end() # finish the previous loop.
File "user/local/lib/python3.4/dist-packages/pi3d/Display.py", line 364, in _loop_end time.sleep(delta) keyboardInterrupt
```

swehner, 2016-08-01:
Hey,

So, to answer your questions:
* Output looks good
* Counters not returning to normal size, means that hello_video.bin runs, but doesn't finish.
Can you check if hello_video.bin is running all the time while the counters are reduced in size?
`ps ax | grep hello_video`

* It's normal that replay is emptied after restart - it is mounted in RAM. So the files are not written again and again to the SD card.

* The traceback you see is normal - it's just that the Ctrl+C is not handled specificially and it just exits forcefully - but that's normal.

I dimly remember us having a similar issue as this - video player hanging and never stopping - and I think it was related to the GPU memory size. Can you check and raise the GPU memory split a bit more?
Try 192M or 256M using raspi-config.
After reboot you can verify that it is set correctly using: `vcgencmd get_mem gp`
Let me know if that changed someting.

swehner, 2016-08-01:
This was the issue I created back then: #5
I remember that it took us quite some time to figure out it was memory related.

danpillay87, 2016-08-01:
ah - ha that seems to have done the trick - a quick up to 256M with raspi-config and we're sorted! excellent shout - for sure wouldn't have isolated memory was the issue alone! thanks @swehner - I'll be taking the table apart first thing tomorrow!

swehner, 2016-08-01:
Awesome! Have fun!

Closed 2016-08-01.

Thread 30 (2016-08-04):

color block

ErnieTheTech, 2016-08-04:
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

Hey everyone, replay and buttons work great. I am waiting on the IR to get here on Monday.
In the meantime, can you tell me what you think the color block is?

Also, when a goal is scored...right before and right after the replay video, you can see the terminal for a few seconds---is that normal?

Thanks in advance
Running GPU at 256

dpaneda, 2016-08-04:
The rainbow icon indicates under-voltage on the raspberry. We also face that problem on our installation. You should try to find another usb charger with a higher voltage to fix that.

We also see the "flickering" problem showing the terminal output on the replays, but in our case it gets solved after some time. I guess that is because the terminal enter power safe mode or something like that. That being said, it would be cool to have that problem fixed, I'm not sure if that is a problem on our software or some kind of bug on pi3d.

swehner, 2016-08-04:
Hi,

So all things are displayed in dispmanx layers on the raspberry in the following order:
* Video
* UI
When playing a video, the UI background is set to transparent, so the video underneath is visible.
And for a short time the console shows through.
As @dpaneda said, after some time the console goes to black, so that shouldn't be an issue...

Regarding the power supply I think you should go with a 2 amp rating at least - we started out with the recommended 1 amp and it wasn't enough.

ErnieTheTech, 2016-08-04:
@dpaneda Thank you for responding. You are most certainly correct about the power. When I tested it at home it was being powered by a Roku USB port but when I got to work it was powered with a stand alone power block and cable---issue resolved.

And yes, when I test it after it has been loaded for a while there is no more terminal displayed

Thanks again guys

Closed 2016-08-04.

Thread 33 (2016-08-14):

Ignoring short goal - duration

danpillay87, 2016-08-14:
hello - when running through my pi i'm constantly getting "ignoring short goal - duration X" being outputted to the console even when event_debug is not enabled as a module - is this expected activity - any reason this would be constantly logging that people might be aware of?

Thanks

swehner, 2016-08-14:
Hey,

Are you actually using the arduino for the goal inputs? This warning is only printed if a goal_event is received and it carries a duration amount that is too small.
So you'd have to check who is actually generating these goal events..
This is printed by the score plugin - not the event_debug plugin.
I'd try to see what is generating these goal events and what their format is.
If you're using an Arduino, do check the serial output in the serial monitor in Arduino IDE and verify what they format of the goal events is.

danpillay87, 2016-08-14:
Seems to be generated by yellow team with source: serial but I'll keep
digging and see if anything else uncovers itself in the logs! Thanks

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

swehner, 2016-08-19:
Hey - if you're still having with issues with this, you can post some output from the serial monitor of the arduino IDE while you're using the arduino (pushing buttons, triggering goals) - Maybe I see something weird.
You can also put some print statements before https://github.com/swehner/foos/blob/master/plugins/io_serial.py#L39
to see what you're Arduino is sending.

danpillay87, 2016-08-20:
thanks - I'm testing this just with arduino IDE and you're right - seems like it's isolated to do with my arduino code - getting a constant output of non-standard characters. Guessing I've compiled the arduino code incorrectly which I'll look into myself but if this has been a problem for anyone else, please feel free to point me in the direction.
[arduino-sketch.txt](https://github.com/swehner/foos/files/428180/arduino-sketch.txt)

danpillay87, 2016-08-20:
ok that was simple - didn't realise baud rate should be 115200 - with that the serial monitor still outputs constantly:

YG 24 908
YG 24 912
YG 32 892
YG 28 904
YG 28 908
YG 20 904
YG 28 920
YG 16 904
YG 16 920
YG 40 920
YG 28 876
YG 32 904
YG 32 904

That's with just the nano attached at the moment, hence the constant output to the PI & crashing - any ideas welcome, hardware is definitely not my area, though I'm doing my upmost!

swehner, 2016-08-20:
So, I think I need some more info on what you're using.
First of all, you're running the .ino file from the repository, right?
I understand that you have connected the IR receiver and Emitter, right? If not - if you just plugin the arduino as it is without connecting anything, the input ports might be floating and this could easily produce this behavior...
There is no pull-down configured on those ports so if there's nothing connected it'll be reading either 1 or 0 randomly.

If you have something connected can you send the part numbers (just in case you have a slightly different component).

Does this also happen with the black IR sensor?

Check if it's something the IR sensor is receiving - see if it stops if you cover it with your hand or a dark plastic cup or something similar.

danpillay87, 2016-08-21:
thanks Swehner - I tried both with and without the ir received and emitter set-up - if I comment out the yellow goal only then all is well so I'm guessing it must just be a hardware issue otherwise the black goal would be triggering as well.

 if (goalsEnabled) {
      //processGoal(d, PIN_MASK_YELLOW, &goalY, &goalTimeY, &offTimeY, GOAL_YELLOW_STR);
      processGoal(d, PIN_MASK_BLACK,  &goalB, &goalTimeB, &offTimeB, GOAL_BLACK_STR);
    }

I'm going to attempt switching the yellow goal pin from pin 10 to pin 12 to see if that resolves the issue.

danpillay87, 2016-08-21:
this seems to have done the trick thankfully in case anyone has any issues.

Closed 2016-08-21.

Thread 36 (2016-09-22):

Button Pins

ErnieTheTech, 2016-09-22:
Hey guys, sorry I have been away. I work for a University and since we started classes last month I have been slammed.

I started up my project again this week and made a button box prototype. LED's work great but I cant seem to figure out the button inputs. If I do them one by one it seems to map this:

D2=-Yellow
D3=+Yellow
D4=-Black
D5=+Black
D6=Replay?

When I put them all connected at once it doesnt seem to work. Buttons start to open menus that I cannot control. Is there something I am doing wrong? Where do I edit the config for button inputs?

Thanks again
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

Essilor84, 2019-05-13:
How you fix that Problem?

Closed 2016-09-23.

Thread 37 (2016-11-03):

"Permission Denied" When running ./check on Test Replays

cloworm, 2016-11-03:
Making a Foosball Table in our fab lab and my colleague is trying to use your project.

Exact error is:

`Running camera...

./check: line 122: 2284 Terminated video/run-camera.sh
video/replay.sh: 12: video/replay.sh: video/player/player: Permission denied`

We tried running the command with sudo and checking the permissions, and we are having trouble solving the issue.

swehner, 2016-11-03:
So, I understand you're running this on the raspberry pi with the pi user.
Did you build the player using: `pushd video/player; make && popd`?
Can you include an output of: `ls -al video/player`?

cloworm, 2016-11-11:
A player was never built manually, no. We looked through the readme but couldn't find any reference to that command - we only saw it referenced in the check file

the output is:
`pi@raspberrypi:~/foos-master $ ls -al video/player
total 220
drwxrwxrwx 3 pi pi 4096 Sep 15 15:07 .
drwxrwxrwx 3 pi pi 4096 Sep 14 15:10 ..
-rwxrwxrwx 1 pi pi 923 Sep 14 15:10 Makefile
drwxrwxrwx 2 pi pi 4096 Sep 15 15:07 player
-rwxrwxrwx 1 pi pi 8622 Sep 14 15:10 video.c
-rwxrwxrwx 1 pi pi 195352 Sep 15 14:50 video.o`

swehner, 2016-11-11:
Hi,

You're right - that step is missig in the Readme. I'll add it - thanks for pointing it out.
So, it looks like kind of weird - becaue video/player seems to be a directory in your case instead of the compiled executable.
Can you go and delete that directory and compile it again?

```
cd video/player
rm -rf player
make
```
It looks like something weird happened there...
This is what it should look like:

```
pi@raspberrypi:~/foos $ ls -al video/player/
total 408
drwxr-xr-x 2 pi pi   4096 Nov 11 15:44 .
drwxr-xr-x 3 pi pi   4096 Aug 27 14:06 ..
-rw-r--r-- 1 pi pi    923 Aug 27 14:06 Makefile
-rwxr-xr-x 1 pi pi 194588 Nov 11 15:42 player
-rw-r--r-- 1 pi pi   8622 Aug 27 14:06 video.c
-rw-r--r-- 1 pi pi 195636 Nov 11 15:38 video.o
```

cloworm, 2016-11-11:
We tried following your instructions and get this error after inputting the `make` command:

```
pi@raspberrypi:~/foos-master/video/player $ make
cc -DSTANDALONE -D__STDC_CONSTANT_MACROS -D__STDC_LIMIT_MACROS -DTARGET_POSIX -D_LINUX -fPIC -DPIC -D_REENTRANT -D_LARGEFILE64_SOURCE -D_FILE_OFFSET_BITS=64 -U_FORTIFY_SOURCE -Wall -g3 -DHAVE_LIBOPENMAX=2 -DOMX -DOMX_SKIP64BIT -ftree-vectorize -pipe -DUSE_EXTERNAL_OMX -DHAVE_LIBBCM_HOST -DUSE_EXTERNAL_LIBBCM_HOST -DUSE_VCHIQ_ARM -Wno-psabi -I/opt/vc/include/ -I/opt/vc/include/interface/vcos/pthreads -I/opt/vc/include/interface/vmcs_host/linux -I./ -I/opt/vc/src/hello_pi/libs/ilclient -I/opt/vc/src/hello_pi/libs/vgfont -c video.c -o video.o -Wno-deprecated-declarations
cc -DSTANDALONE -D__STDC_CONSTANT_MACROS -D__STDC_LIMIT_MACROS -DTARGET_POSIX -D_LINUX -fPIC -DPIC -D_REENTRANT -D_LARGEFILE64_SOURCE -D_FILE_OFFSET_BITS=64 -U_FORTIFY_SOURCE -Wall -g3 -DHAVE_LIBOPENMAX=2 -DOMX -DOMX_SKIP64BIT -ftree-vectorize -pipe -DUSE_EXTERNAL_OMX -DHAVE_LIBBCM_HOST -DUSE_EXTERNAL_LIBBCM_HOST -DUSE_VCHIQ_ARM -Wno-psabi -L/opt/vc/lib/ -lGLESv2 -lEGL -lopenmaxil -lbcm_host -lvcos -lvchiq_arm -lpthread -lrt -lm -L/opt/vc/src/hello_pi/libs/ilclient -L/opt/vc/src/hello_pi/libs/vgfont -o player video.o -lilclient
/usr/bin/ld: cannot find -lilclient
collect2: error: ld returned 1 exit status
Makefile:12: recipe for target 'player' failed
make: *** [player] Error 1
```

```
pi@raspberrypi:~/foos-master/video/player $ ../.././check
Checking environment...

* Binary deps:
[ OK] play (needed for sound) found
[ OK] avconv (needed for upload) found
[ OK] cec-client (needed for standby) found
[ OK] python3 (needed for foos) found
[ OK] pip3 (needed for foos) found

* RaspberryPi specific deps:
[ OK] /opt/vc/bin/raspivid (needed for camera)
[ERR] video/player/player (needed for replay) not found
====> Try: pushd video/player; make && popd

* Replay path:
/usr/bin/python3: Error while finding spec for 'foos.config_getter' (<class 'ImportError'>: No module named 'foos')
[ERR] Replay path should be on a tmpfs filesystem instead of ext2/ext3
[ OK] is writable

* GPU settings:
[ OK] GPU memory set to 192

* evdev input:
[ OK] /dev/input seems readable io_evdev_keyboard should work

* Python deps
[   ] Can't check python3 deps for the moment - if you have issues:
====> Try: pip3 install -r requirements

* Test Replays - press Y to test N to skip

* Finished!

pi@raspberrypi:~/foos-master $ pushd video/player; make && popd
~/foos-master/video/player ~/foos-master
cc -DSTANDALONE -D__STDC_CONSTANT_MACROS -D__STDC_LIMIT_MACROS -DTARGET_POSIX -D_LINUX -fPIC -DPIC -D_REENTRANT -D_LARGEFILE64_SOURCE -D_FILE_OFFSET_BITS=64 -U_FORTIFY_SOURCE -Wall -g3 -DHAVE_LIBOPENMAX=2 -DOMX -DOMX_SKIP64BIT -ftree-vectorize -pipe -DUSE_EXTERNAL_OMX -DHAVE_LIBBCM_HOST -DUSE_EXTERNAL_LIBBCM_HOST -DUSE_VCHIQ_ARM -Wno-psabi -L/opt/vc/lib/ -lGLESv2 -lEGL -lopenmaxil -lbcm_host -lvcos -lvchiq_arm -lpthread -lrt -lm -L/opt/vc/src/hello_pi/libs/ilclient -L/opt/vc/src/hello_pi/libs/vgfont -o player video.o -lilclient
/usr/bin/ld: cannot find -lilclient
collect2: error: ld returned 1 exit status
Makefile:12: recipe for target 'player' failed
make: *** [player] Error 1
```

swehner, 2016-11-11:
Ok, so it looks like you have the examples in /opt/vc/src/hello_pi (on my raspbian it's the package libraspberrypi-doc, in cas you need to install it).
Do run:
```
pi@raspberrypi:/opt/vc/src/hello_pi $ ./rebuild.sh
```
That should hopefully do the trick and generate the missing libraries.
Afterwards compiling the player should work.
Let me know if that did the trick - I'll include it in the check script.

JPrevost, 2016-12-04:
FYI. I ran into the same problem and running `rebuild.sh` does let me get past it. Thanks!

cloworm, 2016-12-06:
Thanks, it did the trick for me also!

illing2005, 2017-06-04:
Thanks!
I had the same problem. Runnig `rebuild.sh` did do the trick.
I think this should be added to the troubleshoot section.

swehner, 2017-06-16:
Was this with the lates version of the code? The newer versions have a custom player exec compiled in video/player - so they shouldn't be using the demo player from the rpi firmware.
If the player doens't exist "check" tells you how to compile it. Hope that helps.

cschaffner, 2017-06-17:
I just had exactly the same error:
```
pi@raspberrypi:~/foos-master $ pushd video/player; make && popd
~/foos-master/video/player ~/foos-master
cc -DSTANDALONE -D__STDC_CONSTANT_MACROS -D__STDC_LIMIT_MACROS -DTARGET_POSIX -D_LINUX -fPIC -DPIC -D_REENTRANT -D_LARGEFILE64_SOURCE -D_FILE_OFFSET_BITS=64 -U_FORTIFY_SOURCE -Wall -g3 -DHAVE_LIBOPENMAX=2 -DOMX -DOMX_SKIP64BIT -ftree-vectorize -pipe -DUSE_EXTERNAL_OMX -DHAVE_LIBBCM_HOST -DUSE_EXTERNAL_LIBBCM_HOST -DUSE_VCHIQ_ARM -Wno-psabi -L/opt/vc/lib/ -lGLESv2 -lEGL -lopenmaxil -lbcm_host -lvcos -lvchiq_arm -lpthread -lrt -lm -L/opt/vc/src/hello_pi/libs/ilclient -L/opt/vc/src/hello_pi/libs/vgfont -o player video.o -lilclient
/usr/bin/ld: cannot find -lilclient
collect2: error: ld returned 1 exit status
Makefile:12: recipe for target 'player' failed
make: *** [player] Error 1
```
 on a new Pi with the latest Raspbian software. Running `rebuild.sh` as above has then allowed me to compile the player.

swehner, 2017-06-17:
Ah ok! That makes sense, that it is due to the libraries - i thought it was because of the player itself. Thanks for reporting! I'll see how to include it!

Closed 2016-12-06.

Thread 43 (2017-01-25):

Arduino connection to RPi

ewoco, 2017-01-25:
I might just be missing something, but:

How does the RPi connect to the arduino? Using the standard TX and RX on both?

swehner, 2017-01-26:
Hey,

The Arduino si connected via a USB cable to the Raspberry Pi (https://github.com/swehner/foos/blob/master/doc/HWSetup.md#raspberry-pi), the same way you'd connect it for programming.
It uses the serial over USB to communicate with the Pi

Closed 2017-01-31.

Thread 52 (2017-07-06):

Ball speed tracker - not an issue :)

bartha-adam, 2017-07-06:
Hi guys, this is not an issue, it's more of a brainstorming :)
Just wanted to start a conversation on this topic, and did not found any reasonable place on github...

Maybe it would be interesting somehow to measure the ball's speed when enters the goal, and then show it after/during the replay...

What do you guys thing?
Any ideas  on this topic?

swehner, 2017-07-08:
That sounds interesting - having two IR barriers in each goal to measure the time it takes to get from one to the other would be fairly easy, and should work without any major issues.
I think we had considered this at some point, but it is a bit tricky to actually attach them physically to the goal - putting them directly on the goal on top of the playing field would have been a lot more difficult on our table.

So in the end we put the sensors under the field on the ball return ramp - before getting there the ball hits the goal's backplate (angled so the ball falls straight down) and then the ramp before rolling by the sensor.
To us it seemed that depending on the angle and the speed of the ball some slowed down a lot more than others when getting to the ramp.
I'm not sure how different the ball speed is at that point from when it actually entered the goal - so maybe measuring it there might always be pretty slow.

If you could place the sensors on top of the field that would be a lot better I guess, but even if it's not always 100% accurate it would be fun to add it - are you planning on trying out something like that?

bartha-adam, 2017-07-12:
I was thinking about the possibility to use computer vision, since in our case, the raspberry camera recording is above the center of the table, directed towards the table.
Unfortunately, even at VGA@90FPS, the ball seems to be pretty blurred....

Other approach would be some kind of pressure sensor added to the goal's backplate, so when a fast ball hits the backplate, the pressure sensor would indicate a higher value...
Not sure if there is any sensor that could measure force/pressure having an area around 5x30cm....

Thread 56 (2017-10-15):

No module named 'evdev'

stevenb9, 2017-10-15:
I'm very sorry to bother you again but when running the ./foos.py I get following output using the default config:

```
pi@raspberrypi:~/Desktop/foos $ ./foos.py
   INFO - Foos v20160814 starting
   INFO - Blank console
display:2 format:XRGB8888 transform:0 layer:-127 src:0,0,1440,900 dst:0,0,1440,900 cost:889 lbm:0
display:2 format:YUV_UV transform:0 layer:2 src:0,0,1280,720 dst:0,0,128,72 cost:1429 lbm:2048
Patching create surface to fix alpha
   INFO - Display 1440x900@25
glGetError 0x500
glGetError 0x500
glGetError 0x500
glGetError 0x500
glGetError 0x500
glGetError 0x500
glGetError 0x500
glGetError 0x500
glGetError 0x500
glGetError 0x500
glGetError 0x500
glGetError 0x500
glGetError 0x500
glGetError 0x500
glGetError 0x500
glGetError 0x500
glGetError 0x500
glGetError 0x500
glGetError 0x500
   INFO - Loading plugins {'sound', 'game', 'league', 'io_debug', 'control', 'score', 'standby', 'leds', 'io_evdev_keyboard', 'menu', 'io_serial'}
Traceback (most recent call last):
  File "./foos.py", line 50, in <module>
    PluginHandler(bus)
  File "/home/pi/Desktop/foos/foos/plugin_handler.py", line 16, in __init__
    self.load(bus)
  File "/home/pi/Desktop/foos/foos/plugin_handler.py", line 23, in load
    module = importlib.import_module('plugins.' + plugin)
  File "/usr/lib/python3.5/importlib/__init__.py", line 126, in import_module
    return _bootstrap._gcd_import(name[level:], package, level)
  File "<frozen importlib._bootstrap>", line 986, in _gcd_import
  File "<frozen importlib._bootstrap>", line 969, in _find_and_load
  File "<frozen importlib._bootstrap>", line 958, in _find_and_load_unlocked
  File "<frozen importlib._bootstrap>", line 673, in _load_unlocked
  File "<frozen importlib._bootstrap_external>", line 673, in exec_module
  File "<frozen importlib._bootstrap>", line 222, in _call_with_frames_removed
  File "/home/pi/Desktop/foos/plugins/io_evdev_keyboard.py", line 2, in <module>
    import evdev
ImportError: No module named 'evdev'
```
This was fixed doing pip install evdev

```
When enabling the 3 camera plugins in the config i get this output:
pi@raspberrypi:~/Desktop/foos $ ./foos.py
   INFO - Foos v20160814 starting
   INFO - Blank console
display:2 format:XRGB8888 transform:0 layer:-127 src:0,0,1440,900 dst:0,0,1440,900 cost:889 lbm:0
display:2 format:YUV_UV transform:0 layer:2 src:0,0,1280,720 dst:0,0,128,72 cost:1429 lbm:2048
Patching create surface to fix alpha
   INFO - Display 1440x900@25
glGetError 0x500
glGetError 0x500
glGetError 0x500
glGetError 0x500
glGetError 0x500
glGetError 0x500
glGetError 0x500
glGetError 0x500
glGetError 0x500
glGetError 0x500
glGetError 0x500
glGetError 0x500
glGetError 0x500
glGetError 0x500
glGetError 0x500
glGetError 0x500
glGetError 0x500
glGetError 0x500
glGetError 0x500
   INFO - Loading plugins {'score', 'io_serial', 'leds', 'io_debug', 'camera', 'standby', 'league', 'game', 'replay', 'sound', 'motiondetector', 'menu', 'control', 'io_evdev_keyboard'}
  ERROR - No ttyUSB device available
Traceback (most recent call last):
  File "./foos.py", line 50, in <module>
    PluginHandler(bus)
  File "/home/pi/Desktop/foos/foos/plugin_handler.py", line 16, in __init__
    self.load(bus)
  File "/home/pi/Desktop/foos/foos/plugin_handler.py", line 23, in load
    module = importlib.import_module('plugins.' + plugin)
  File "/usr/lib/python3.5/importlib/__init__.py", line 126, in import_module
    return _bootstrap._gcd_import(name[level:], package, level)
  File "<frozen importlib._bootstrap>", line 986, in _gcd_import
  File "<frozen importlib._bootstrap>", line 969, in _find_and_load
  File "<frozen importlib._bootstrap>", line 958, in _find_and_load_unlocked
  File "<frozen importlib._bootstrap>", line 673, in _load_unlocked
  File "<frozen importlib._bootstrap_external>", line 673, in exec_module
  File "<frozen importlib._bootstrap>", line 222, in _call_with_frames_removed
  File "/home/pi/Desktop/foos/plugins/motiondetector.py", line 3, in <module>
    from inotify_simple import INotify, flags
ImportError: No module named 'inotify_simple'
```
the camera plugins are running after installing an older version of the inotify_simple: pip install inotify_simple==1.0.3

swehner, 2017-10-15:
All these modules are in the requirements.txt file: did you try to do:
pip3 install -r requirements.txt

That should have installed all requirements

stevenb9, 2017-10-15:
I did try that command but it would fail when installing Pillow (all other packages were installed), error was something like.. pillow cant find required dependencies for compilation. I manually installed Pillow 2.9.0 which seemed to fix my problem there

Closed 2019-01-28.

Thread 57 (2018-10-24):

Replay did not work

LukeSeinVadder, 2018-10-24:
Hi,
I have a little problem,

first I have to write in english ;)
und second, the replay make an error,
everytime when a ball go throuh the IR LED and the IR Emitter, or when I use replay button..
 The Score works , but the replay is not comming.
In the upper right corner there is a little picture of the camera, which is working.
Everytime foos want to play the replay, the score try to go in the backround, for an half of a second, and came directly back.

This file is made:                   /dev/shm/replay/fragments/out0026.h264
but the long and the short file are not generated.

Here is the code and I hope someone can help me, I build the foos with all parts and all introductions from this page.

Thanks for ur help

In this code , I use the IR barrier to make a goal.
```
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
```
In this code I use the replay button

(with motionsdetector, by the way, I dont unterstand why ( people_stop_playing) all the time...)

```
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
```

swehner, 2018-10-27:
Hi there,

From the log files it looks like your IR barriers are maybe not working correcty - it seems they generate too short bursts and that's why it's ignoring them and not running the replay (see the Ignoring short goal messages). If they are correct and you want to lower the min time there's a config value for that: min_goal_usecs you can try to tweak.

To see if the video files are generated correctly can you run the scripts by hand from a terminal or from an ssh session?
Can you also check if the chunks are generated correctly?

`$ ls -lrt /dev/shm/replay`

With the foos running and the camera recording you should be able to run:

`$ video/generate-replay.sh /dev/shm/replay 1 25 10`

See if that works and if it generates the long/short video files.
Then try to run the player

`$ video/replay.sh /dev/shm/replay/replay_short.h264 25`

Try to see if any of these commands throw an error. BTW: I assume you've compiled the player:

`pi@raspberrypi:~/foos $ pushd video/player; make && popd`

Try to run the commands by hand and see if any of them output any errors, maybe then we can find out what's wrong.

LukeSeinVadder, 2018-10-27:
Hi,

thanks for your answers of my questions.
when I set the `min_goal_usecs = 100` then I dont get back the durations. A greater number then 100 then duratios come back. But the replay dont work.

```
pi@raspberrypi:~/foos $ python3 foos.py
   INFO - Foos v20160814 starting
   INFO - Blank console
display:2 format:XRGB8888 transform:0 layer:-127 src:0,0,1824,984 dst:48,48,1824,984 cost:1103 lbm:0
display:2 format:YUV_UV transform:0 layer:2 src:0,0,1152,720 dst:0,0,115,71 cost:1301 lbm:2048
Patching create surface to fix alpha
   INFO - Display 1920x1080@25
   INFO - Loading plugins {'io_serial', 'io_evdev_keyboard', 'leds', 'camera', 'game', 'menu', 'io_debug', 'replay', 'control', 'league', 'score', 'sound', 'motiondetector'}
   INFO - Opening /dev/ttyUSB0
   INFO - Reading key events from: [InputDevice('/dev/input/event0')]
   INFO - Run GUI
   INFO - Watching /dev/shm/replay/fragments
   INFO - Setting game mode 10 None
   INFO - people_stop_playing
   INFO - Ignoring goal command yellow happening too soon
   INFO - Ignoring goal command yellow happening too soon
   INFO - Ignoring goal command yellow happening too soon
   INFO - Ignoring goal command yellow happening too soon
  ERROR - ['video/replay.sh', '/dev/shm/replay/replay_short.h264', '25'] returned 254
   INFO - Ignoring goal command yellow happening too soon
   INFO - Ignoring goal command yellow happening too soon
   INFO - Ignoring goal command yellow happening too soon
  ERROR - ['video/replay.sh', '/dev/shm/replay/replay_short.h264', '25'] returned 254
   INFO - Ignoring goal command yellow happening too soon
   INFO - Ignoring goal command yellow happening too soon
.   INFO - Restore console
display:2 format:XRGB8888 transform:0 layer:-127 src:0,0,1824,984 dst:48,48,1824,984 cost:1103 lbm:0
display:2 format:RGB888 transform:0 layer:-1 src:0,0,938,528 dst:0,0,1920,1080 cost:1186 lbm:15360
display:2 format:RGBA32 transform:20000 layer:1 src:0,0,1920,1080 dst:0,0,1920,1080 cost:1156 lbm:0
display:2 format:YUV_UV transform:0 layer:2 src:0,0,1152,720 dst:0,0,115,71 cost:1301 lbm:2048
pygame 1.9.4
Hello from the pygame community. https://www.pygame.org/contribute.html
pi@raspberrypi:~/foos $ ´
```
When I only use the replaybutton

```
pi@raspberrypi:~/foos $ python3 foos.py
   INFO - Foos v20160814 starting
   INFO - Blank console
display:2 format:XRGB8888 transform:0 layer:-127 src:0,0,1824,984 dst:48,48,1824,984 cost:1103 lbm:0
display:2 format:YUV_UV transform:0 layer:2 src:0,0,1152,720 dst:0,0,115,71 cost:1301 lbm:2048
Patching create surface to fix alpha
   INFO - Display 1920x1080@25
   INFO - Loading plugins {'replay', 'leds', 'io_debug', 'io_serial', 'score', 'control', 'motiondetector', 'game', 'sound', 'camera', 'menu', 'io_evdev_keyboard', 'league'}
   INFO - Opening /dev/ttyUSB0
   INFO - Watching /dev/shm/replay/fragments
   INFO - people_stop_playing
   INFO - Reading key events from: [InputDevice('/dev/input/event0')]
   INFO - Run GUI
   INFO - Setting game mode 10 None
  ERROR - ['video/replay.sh', '/dev/shm/replay/replay_long.h264', '25'] returned 25
```

The fragments are working all the time, and the file works in this folder  (out0027.h264)

ls -lrt /dev/shm/replay
```
pi@raspberrypi:~ $ ls -lrt /dev/shm/replay
insgesamt 0
drwxr-xr-x 2 pi pi 80 Okt 27 19:20 fragments
```

I assume you've compiled the player:

pi@raspberrypi:~/foos $ pushd video/player; make && popd
~/foos/video/player ~/foos
make: „player“ ist bereits aktuell.
~/foos

that looks good and is to date.

the short and the long replays are not comming, so i cannot play them.

Sometimes I close the foos program and this code is generated, normaly this dont happen.

```
pi@raspberrypi:~/foos $ python3 foos.py
   INFO - Foos v20160814 starting
   INFO - Blank console
display:2 format:XRGB8888 transform:0 layer:-127 src:0,0,1824,984 dst:48,48,1824,984 cost:1103 lbm:0
display:2 format:YUV_UV transform:0 layer:2 src:0,0,1152,720 dst:0,0,115,71 cost:1301 lbm:2048
Patching create surface to fix alpha
   INFO - Display 1920x1080@25
   INFO - Loading plugins {'replay', 'leds', 'io_debug', 'io_serial', 'score', 'control', 'motiondetector', 'game', 'sound', 'camera', 'menu', 'io_evdev_keyboard', 'league'}
   INFO - Opening /dev/ttyUSB0
   INFO - Watching /dev/shm/replay/fragments
   INFO - people_stop_playing
   INFO - Reading key events from: [InputDevice('/dev/input/event0')]
   INFO - Run GUI
   INFO - Setting game mode 10 None
  ERROR - ['video/replay.sh', '/dev/shm/replay/replay_long.h264', '25'] returned 254
  ERROR - ['video/replay.sh', '/dev/shm/replay/replay_long.h264', '25'] returned 254
  ERROR - ['video/replay.sh', '/dev/shm/replay/replay_long.h264', '25'] returned 254
  ERROR - ['video/replay.sh', '/dev/shm/replay/replay_long.h264', '25'] returned 254
.   INFO - Restore console
display:2 format:XRGB8888 transform:0 layer:-127 src:0,0,1824,984 dst:48,48,1824,984 cost:1103 lbm:0
display:2 format:RGB888 transform:0 layer:-1 src:0,0,938,528 dst:0,0,1920,1080 cost:1186 lbm:15360
display:2 format:RGBA32 transform:20000 layer:1 src:0,0,1920,1080 dst:0,0,1920,1080 cost:1156 lbm:0
display:2 format:YUV_UV transform:0 layer:2 src:0,0,1152,720 dst:0,0,115,71 cost:1301 lbm:2048
pygame 1.9.4
Hello from the pygame community. https://www.pygame.org/contribute.html
Exception in thread Thread-17:
Traceback (most recent call last):
  File "/usr/lib/python3.5/threading.py", line 914, in _bootstrap_inner
    self.run()
  File "/usr/lib/python3.5/threading.py", line 862, in run
    self._target(*self._args, **self._kwargs)
  File "/home/pi/foos/plugins/io_evdev_keyboard.py", line 86, in writer_thread
    self.write_queue.get()
  File "/usr/lib/python3.5/multiprocessing/queues.py", line 94, in get
    res = self._recv_bytes()
  File "/usr/lib/python3.5/multiprocessing/connection.py", line 216, in recv_bytes
    buf = self._recv_bytes(maxlength)
  File "/usr/lib/python3.5/multiprocessing/connection.py", line 407, in _recv_bytes
    buf = self._recv(4)
  File "/usr/lib/python3.5/multiprocessing/connection.py", line 383, in _recv
    raise EOFError
EOFError

Exception in thread Thread-8:
Traceback (most recent call last):
  File "/usr/lib/python3.5/threading.py", line 914, in _bootstrap_inner
    self.run()
  File "/usr/lib/python3.5/threading.py", line 862, in run
    self._target(*self._args, **self._kwargs)
  File "/home/pi/foos/plugins/io_serial.py", line 51, in writer_thread
    line = self.write_queue.get()
  File "/usr/lib/python3.5/multiprocessing/queues.py", line 94, in get
    res = self._recv_bytes()
  File "/usr/lib/python3.5/multiprocessing/connection.py", line 216, in recv_bytes
    buf = self._recv_bytes(maxlength)
  File "/usr/lib/python3.5/multiprocessing/connection.py", line 407, in _recv_bytes
    buf = self._recv(4)
  File "/usr/lib/python3.5/multiprocessing/connection.py", line 383, in _recv
    raise EOFError
EOFError
```

I build the foos with the components from your list, und I use the fritzing JPEG.
Do you use the capacitor with 100nF and the 100Ω  resistor for the IR emitter, I use this.
I tested it, they also work without them.

BTW:
The 4 pin buttons work, but I dont know if I correctly connected them.

                                                     +
                                                     o
                                       2A250VAC  o      o
                                                     o
                                                     -
Example LED 3 from the fritzing jpeg:

(+) and (2A250VAC)  , i put to A0 on the Arduino
(-) to Ground
and the right last pin to D2 from the NANO

When I push the buttons they work correctly,  but dont flash up the LEDs.
when the IR barrier make a goal , all 5 buttons LEDS flashes.

Is this correct ?

LukeSeinVadder, 2018-11-01:
Hi,

now I have the right camera... V2 is now installed. Bevor I had the 1.3 Version, my fault.
But the problem is still there.
Should I try to make a full new installation of the the Pi ?

The only error comes here.

```
pi@raspberrypi:~/foos

 $ /opt/vc/bin/raspivid -o /dev/shm/replay/fragments/out%04d.h264 -x
mmal: mmal_vc_component_enable: failed to enable component: ENOSPC
mmal: camera component couldn't be enabled
mmal: main: Failed to create camera component
mmal: Failed to run camera app. Please check for firmware updates`

```

swehner, 2018-11-01:
Hi,

First of all, sorry - I didn't mean to imply you needed to change the camera module, both v1 and v2 should work fine.
As the problem seems to be related to the camera and the raspivid process I just wanted to get some more information.

Also when you post your comments, don't edit them deleting helpful information cause it's harder to follow up for others when reading - just add a new comment with your new finding :)
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
swehner, 2018-11-05:
Hey,

I'm glad to hear that it worked out in the end! 384mb should be more than enough, I think.
The video_size is for the camera recording.. I don't think it should be important what monitor you're using, but more importantly the supported modes of the camera.
You can find more info here: https://www.raspberrypi.org/documentation/hardware/camera/

About the errors when exiting foos i wouldn't worry too much, it's an unhandled exception but it shouldn't cause any problems.

I'm resoling the issue - feel free to reopen if you still have trouble!

Closed 2018-11-05.

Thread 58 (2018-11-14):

IR Barrier works not correctly

LukeSeinVadder, 2018-11-14:
Hello there,

I have a little new problem, maybe you can help me.
Yesterday we installed the hole project in the tablekicker. At the beginning it all looks wonderful.
We installed the IR Barrier and tested it with the ball 200 times :), when the kickertable was open with normal light evironment.
Then we closed the table and start playing /  the IR Barrier only works in the dark table, when the ball runs directly in front of the IR LED. When the ball runs in the middle auf the barrier nothing happens....
We have no white ground in the table , it is wood-optic.
The IR LED is installed like yours in the little hole.

min_goal_usecs parameter is 100

swehner, 2018-11-17:
Sorry for the belated response. If it works when the table is open, but it doesn't work corectly when it is closed it's most likely due to light reflecting of the surfaces.

I would try to put something like black paper or cardbord on the surfaces between the IR LED and the receiver, both on the bottom and on the top to try and see if that helps.
maybe you can also try to put a little duct-tape in front of he emitting led and punch a hole in it to let less light through...

LukeSeinVadder, 2018-11-22:
Hi again,

we solved the problem with 1cm of  shrinking tube over the IR-Emitter , so the signal direction is straight to the IR-LED, and when the ball passes the barrier , it is interupted.

swehner, 2018-11-24:
Awesome! Yeah, it usually takes a bit of fiddling around with the LED/Receivers. I guess it also depends on how thick the wood is and how it directs the beam.
Glad you got it working!

Closed 2018-11-24.

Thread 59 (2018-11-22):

Crontab / job

LukeSeinVadder, 2018-11-22:
Me again, sorry ;)

I want to make foos as a autostart program, when I put it into a crontab, foos is starting , but the camera is not starting with it.

```@reboot /usr/bin/python3 /home/pi/foos/foos.py```

Have you got an idea, how I can realize this, that the rasperry automatically starting it.

BTW, do you really use the V2 Camera, we must go back 2 meters to see the hole table... now we use the 1.3 camera the lense could be nearer to the table.

swehner, 2018-11-24:
So, you can definitely use the v1 camera... In my previous messages I didn't want to imply that you needed v2 - I just wanted to know which one you were using.
I didn't realize they had different lenses - so whatever works best.

swehner, 2018-11-24:
Regarding running something on startup you can also try to use rc.local: https://www.raspberrypi.org/documentation/linux/usage/rc-local.md
If the camera isn't running maybe there's some issue with the environment and it doesn't find the required binaries/libraries. Check if something's in the log file in /dev/shm/foos_event.log.
Maybe also running it and redirecting the error and console output to a file might help to see if something's wrong...

swehner, 2018-11-24:
BTW: here's also some documentation on how the FOV changes depending on the selected camera mode: https://picamera.readthedocs.io/en/release-1.12/fov.html that might be interesting. Maybe you want to play with the parameters to see if it gets better using a different resolution!

LukeSeinVadder, 2019-01-11:
Happy new year !

Excuse me, that I write back late, but I have little time the last 2 month for this projekt.
After many many problems, now we are finished with this projekt.
The camera now works great und all things are ok.
The only problem is to start it automatically in the rpi, I made the job with the rc-local, but it still doesnt work. And I forget to check the event.log, I will make this next time , when I have the rpi at home.

Here are some pictures, how we solve the LCD and camera position with a metal stand and the buttons in the side of the table, enjoy it, and I hope this pictures are an inspiration for other to build this project.

Thanks a lot for your time to help me.

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

swehner, 2019-01-13:
Happy new year to you, too!
That is a pretty awesome build! Thanks for sharing the pictures - would you mind if I post/link them on the project site as your build?

Regarding the rc.local issue: do check the syslog (not sure if something is output there).

LukeSeinVadder, 2019-01-13:
Hello there,

it's my honor, you're welcome to link it on the project page.
When you consider that it's my first project, I've got it all right with your help 😂

Now I have to clone und save the SD - card 😎 , I dont think that I can build it two times.
So many information and reading internet sites to understand just a little bit, how you build this project.
It an awesome work !!!

jeanmichelbouchard, 2019-01-14:
Thanks for the cue! I am implementing that version of raspberry only but the doc is pretty light for it. I will try with that pin for the PWM clock. I think it’s different than what I tried.

Good night!
Jean-Michel

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

swehner, 2019-01-14:
Yes, I know there isn't much doc... If you take some notes I'll be more than happy to add them to the doc here: https://github.com/swehner/foos/blob/master/doc/HWSetup.md#setup-without-an-arduino

Basically you should just need to enable to raspberry plugin and add the config for the pins.
See https://github.com/swehner/foos/blob/master/config.py.sample#L28-L39

The wiring should be pretty much the same as for the arduino...

jeanmichelbouchard, 2019-01-18:
I have another question. On the wiring diagram there is a capacitor on each receiver and also a 100 ohms resistor but they aren’t on the shopping list. Are they necessary?

Jean-Michel

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

jeanmichelbouchard, 2019-01-19:
My Goal detectors work! I will send you a schematic for Pi-only version when finished. I now have a weird problem with my buttons. The program only detects one out of three or four pushs. With a custom program the button is detected correctly. Did you have such a problem? I am searching for an explanation. Also, is there an easy way to not display the background to see the console while running?

Thanks for your answers, really appreciated :)
Jean-Michel

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

swehner, 2019-01-19:
To keep having the console I'd recommend connecting over ssh to your RaspberryPi and running foos from the ssh terminal you're using. If you don't want/can't do this you can start commenting out the code that creates the background, but that'll be a bit trickier:
* https://github.com/swehner/foos/blob/master/foos/ui/ui.py#L346-L354
* https://github.com/swehner/foos/blob/master/foos/ui/ui.py#L499

Re: the buttons - what custom program are you using? Are you using the same code used as here?
https://github.com/swehner/foos/blob/master/plugins/io_raspberry.py#L20
Does it miss short button presses (maybe play with the debounce time)?

jeanmichelbouchard, 2019-01-19:
Got it, I reduced the debounce time and it solved the problem pretty well.

Jean-Michel

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

swehner, 2019-01-19:
Nice! I've added some documentation on how to start foos from rc.local that @LukeSeinVadder asked about here: https://github.com/swehner/foos/blob/master/doc/Installation.md#start-foos-on-boot
That worked fine for a clean installation from scratch.
Let me know if that works for you so I can close this issue! Thanks!

LukeSeinVadder, 2019-01-21:
Hi back again ,

```20:36:30    INFO __main__ - Foos v20160814 starting
20:36:30   ERROR foos.process - /bin/sh: 1: video/blank_console.sh: not found
20:36:30   ERROR foos.process - video/blank_console.sh blank returned 127
20:36:30    INFO foos.ui.ui - Display 1280x720@25
20:36:34    INFO foos.plugin_handler - Loading plugins {'score', 'sound', 'leds', 'camera', 'menu', 'replay', 'control', 'io_debug', 'game', 'io_serial', 'league'}
20:36:34    INFO plugins.io_serial - Opening /dev/ttyUSB0
```

I cant start the program in the rc.local, this is from the foos event.log.

The program try to start for 1 second with the foos backround and end it directly.

swehner, 2019-01-21:
Looks like there's some issue with the path. Are you using the foos.sh in rc.local I've pushed the other day?
I'm asking because this should be running it in the correct path
https://github.com/swehner/foos/commit/35a857fc9761e2ecb7bc992e00a894502845eb39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

If this is the only problem (which I doubt) you could also disable it by adding `blank_console = False` to your config.py.

jeanmichelbouchard, 2019-01-24:
Hi!
Did you get my question about how to create players and launch the tournament in the tournament app?

Here is some code I changed to parametrize and randomize the winner strings that appear when a goal is made. You can put the strings you want in the config and each time a random one is displayed.

In ui.py :

class WinnerString:
    def __init__(self, shader, teams=["yellow", "black"]):
        font = img("Ubuntu-B.ttf")
        duration = 5
        drop_duration = 0.2
        self.shapes = {}
        for i, team in enumerate(teams):
            self.shapes[team] = []
            for j, winnerString in enumerate(config.winner_strings):
#                print(winnerString.format(utils.teamName(team).capitalize())) #debug
                s = FixedOutlineString(font, winnerString.format(utils.teamName(team).capitalize()), outline_size=2, font_size=180, shader=shader)
                s = Move(Disappear(s.sprite, duration=duration), duration=drop_duration)
                self.shapes[team].append(s)

    def draw(self):
        for team, s in self.shapes.items():
            for shape in s:
                shape.draw()

    def show_winner(self, team):
        for t, s in self.shapes.items():
            if team == t:
                shape = random.choice(s)
                shape.position(0, 650, 40)
                shape.moveTo((0, 330, 40), (1, 1, 1))
                shape.show()
            else:
                for shape in s:
                    shape.hide()

In config.py :

# Winner strings
winner_strings = ["Victoire des {}!","Des kings les {}!","Les {} déchirent!","Trop forts les {}!","Faites place aux {}!","You rock !!!"]

--
Jean-Michel Bouchard, ing.
(418) 956-FIJI (3454)
---------------------------------------------------

swehner, 2019-01-24:
The foos-tournament is written by a friend with whom we built the whole
setup. I'm not too familiar with the commands of setting up a league -
maybe you can open an issue in the github project and ask there...

Choosing different winner strings might be ineresting!
You can make a pull request so we can review the changes.
Please keep in mind that the default data should always be in english.
Although we should look into internationalizing it and supporting other
languages...

On Thu, Jan 24, 2019, 03:20 jeanmichelbouchard <notifications@github.com>
wrote:

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

LukeSeinVadder, 2019-01-25:
Hello there,
Yesterday I made a complete new installation of a new SD card and lo and behold it all works.
The startup works wonderfully.
Thus, the topic can now be closed here.
Thank you again.

swehner, 2019-01-25:
Awesome. Closing the issue!

Closed 2019-01-25.

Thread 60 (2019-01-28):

Arduino push buttons and leds don't work with IR barrier

Metanolo76, 2019-01-28:
Hi,
I'm not an arduino expert, forgive me:
when I connect only push buttons and less to Arduino, they work well.
if I also connect IR barrier, buttons and leds stop working (IR works fine).
Any Idea?

I use a compatible arduino UNO, can this be the reason?

Thanks.

swehner, 2019-01-28:
Hey! No worries - it's a bit difficult to fin out what's going on without more information...
Have you tested the serial port?
Can you connect to it  (115200 baud) and see what it outputs?
My guess is that the IR barriers are not working correctly and are triggering all the time, causing the buttons not be processed:

https://github.com/swehner/foos/blob/master/foos_arduino/foos_arduino.ino#L143

Here you can see the code short-circuits in case a goal is detected...
You should be seeing this information in the serial output.
I'd review that the detectors are correctly connected.

I doubt there's an issue with the board itself  (I think the UNO and nano are practically the same board where the I/O is concerned).
I think they use the same atmega328 chip and have the same pinout. Can you confirm what revision of the board your'e using just in case?

Metanolo76, 2019-01-29:
HI,
thanks for answer.
The board in a "Arduino Uno" COMPATIBLE with ATMEGA328P-AU Atmel

This in serial port output:

**`Start with all connect:**
19:45:35.080 -> P
19:45:36.323 -> BG 64 1235104

**1° goal PIN 11**
19:46:58.741 -> BG 81989416 816
19:46:58.923 -> BG 72 171964

**1° goal pin 10**
19:47:33.309 -> YG 616 452872
19:47:33.309 -> YG 180 620
19:47:33.309 -> YG 300 848
19:47:33.309 -> YG 2196 1236

**2° goal PIN 11**
19:48:02.627 -> BG 63355744 392
19:48:02.627 -> BG 212 360

**2° goal pin 10**
19:48:24.910 -> YG 51325028 300
19:48:24.910 -> YG 1712 364
19:48:24.910 -> YG 280 2972
19:48:25.335 -> YG 640 428128
19:48:25.335 -> YG 636 2584
19:48:25.335 -> YG 3420 1208
19:48:25.373 -> YG 1572 300

**3° goal PIN 11**
19:48:59.821 -> BG 56717088 156768

**3° goal pin 10**
19:49:25.216 -> YG 59525520 284
19:49:25.216 -> YG 1152 608
19:49:25.216 -> YG 1432 696
19:49:25.216 -> YG 532 676
19:49:25.678 -> YG 432 467180
19:49:25.678 -> YG 380 3028
19:49:25.678 -> YG 1748 276

**Buttons not works….**

**disconnect IR Pins…**

**Only Buttons**

9:52:51.789 -> P
19:52:56.814 -> P
19:53:01.847 -> P
19:53:06.900 -> P
19:53:09.791 -> OK_D
19:53:09.936 -> OK_U
19:53:11.917 -> P
19:53:16.951 -> P
19:53:21.762 -> BI_D
19:53:21.972 -> BI_U
19:53:21.972 -> P
19:53:25.336 -> BD_D
19:53:25.548 -> BD_U
19:53:27.010 -> P
19:53:28.195 -> YI_D
19:53:28.445 -> YI_U
19:53:30.837 -> YD_D
19:53:31.017 -> YD_U
19:53:32.032 -> P
19:53:37.055 -> P

Thanks.

swehner, 2019-01-31:
So, yeah it looks like the IR detectors are triggering quite frequently...
The way the Arduino is set up it's constantly polling the button states, as soon as a falling edge is detected it stops reading the button and waits for the rising edge.
So there's definitely something wrong with your IR detector...
What power source are you using? Sometimes the USB chargers provide a very noisy power line that might cause issues
You can check the caps at the IR detector in the schematic - I think these should help to stabilize the power input.

The arduino also has a test mode. You enable it by writing "t" to the serial port where it routes the IR inputs to A0 and A2 outputs. Sometimes this helps to see what's happening and if it's working more or less...

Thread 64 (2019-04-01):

38khz pwm only to+  IR led or to + ir receiver too?

Essilor84, 2019-04-01:
Hi , i want to Build raspberry only.
How i connect the 38khz Signal?
Pwm——> resistor—->+ led i think Thats right?
I have to use the pwm for Receiver too?
Or i only use 5v —->resistor——>+ ir receiver?
Sry for na Bad english, its my First rapsberry project But i want to tune my Kicker :)

jeanmichelbouchard, 2019-04-01:
Hi Essilor84, you can check on my fork of the project I have provided a schéma for the Pi-only setup. I didn’t do a pull request yet. Let me know if it suits your need.
https://github.com/jeanmichelbouchard/foos/blob/master/doc/HWSetup.md

swehner, 2019-04-01:
@jeanmichelbouchard looks nice! i'd appreciate a pull request :)
Q1 is a transistor to avoid driving the emitter leds directly from the raspberry pi (or the arduino). There's a limit on how many current a pin can provide - so you basically use the transistor to turn the leds connected to the power supply on and off at the frequency provided by the pwm pin.

Essilor84, 2019-04-16:
i Test it on a breadboard . It works very well ! Thanks for your help.
How i can change the background picture?
Greetings jochen

swehner, 2019-04-18:
Nice! You can put images in img/bg and they should be loaded and rotated automatically.
Folder for bg images: https://github.com/swehner/foos/tree/master/img/bg
Config for switching bg: https://github.com/swehner/foos/blob/master/config_base.py#L7
You can override this value in your config.py if you want to change the time it takes to rotate...

Closed 2019-04-18.

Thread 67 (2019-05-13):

Button Pins dont work....

Essilor84, 2019-05-13:
Hi, if i use smd push Buttons i works well.
Now i want to use LED-Arcade push Buttons.
I Check Every Connection with multimeter, its Looks perfect nur the Pins works only sporadically.
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
I use raspi only Version.
WHO has a Idea?
Thanks and Greets ,Jochen

Essilor84, 2019-05-13:
If i Hammer the buttons (2-3 Times per Second ) its works...??

Essilor84, 2019-05-15:
its possible to log something? Whats Happen Wehen i Push the Button?

Essilor84, 2019-05-17:
i think there is a Problem with debounce:/ if i solder microswitches all works....

swehner, 2019-05-20:
It's hard to tell... you don't happen to have something like an oscilloscope to see what the switch is actually doing, right?
I would try to put a print statement here https://github.com/swehner/foos/blob/master/plugins/io_raspberry.py#L26 to see how often this callback function is actually triggered.
You can try to set bouncetime to 0 see how often it's actually triggering (maybe it's constantly).
Maybe you can try the suggestions to add a capacitor around the switch like it's suggested here: https://sourceforge.net/p/raspberry-gpio-python/wiki/Inputs/

Essilor84, 2019-05-29:
i Play with debounce Time = no change.
I try Hardware Solution (capacitator)= no change.
Now i solder a not quick but very,very Dirty Solution ;).
It works :)!!
![Uploading C86A6D7A-A504-4F05-A4E1-7DE22633C1E3.jpeg…]()

Closed 2019-06-21.

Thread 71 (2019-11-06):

what PNP transistor to use

masseyjeremy, 2019-11-06:
I plan to try this project out. I'm new to PNP transistors. Can you help me know which one I should buy for this?

swehner, 2019-11-07:
Hey, basically any transistor is fine to use for these low power applications. It's basically just to not drive the LEDs directly from the Arduino (even though you could porbably power them directly).
You can find sample schemas on other sites - eg. here is a NPN config with a popular and cheap transistor: https://www.petervis.com/Raspberry_PI/Driving_LEDs_with_CMOS_and_TTL_Outputs/Driving_an_LED_Using_Transistors.html
Here are some other recommendations: https://www.baldengineer.com/the-best-4-transistors-to-keep-in-your-parts-kit.html
I guess it depends a bit on where you're going to buy them...

masseyjeremy, 2019-11-09:
Thanks for the response. Your BOM list mentioned a PNP resistor. So it can be PNP or NPN? I googled the difference and found this: "The main difference between the NPN and PNP transistor is, an NPN transistor turns on when the current flows through the base of the transistor. A PNP transistor turns ON, when there is no current at the base of the transistor." So I just want to make sure I get the right type and dont break something. :)

swehner, 2019-11-10:
So, as the NPN for a LED driver is the more common setup, I've updated the schematics to use an NPN transistor and I've updated the parts list.
I think the most common one you'll find is the BC548, although there are several other cheap alternatives!
You can see some here: https://en.wikipedia.org/wiki/BC548
I'm gonna resolve the Issue, but feel free to reopen in case you have any more questions!
Thanks!

Closed 2019-11-10.

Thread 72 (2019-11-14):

Goals keep registering as long as LED is pointing at receiver, and stops when it is blocked

masseyjeremy, 2019-11-14:
Hi, so i wired up the schematic for the pi-only version, using a PNP transistor. It is working!! However, rather than registering a goal when the sensor is blocked, it is registering goals when the sensor is not blocked. As long as the IR is pointed at the sensor, it keeps adding more and more goals. As soon as I block it with my hand, it stops adding goals. So it seems exactly opposite of what I need it to do. Is there a setting somewhere to fix this and reverse the logic? Or maybe I have this wired up wrong somewhere?
Edit: Some additional info: I am using Vishay TSHF6410 IR LEDs and Vishay TSSP58038 IR Receivers, as mentioned in the BOM list. So far I have only wired up one receiver & led for my testing, assuming that both dont need wired up to do this test.
Edit2: Now that I played around with it more, actually it seems to be working correctly as long as I have the LED almost touching the sensor. I think when i had it further away maybe the led was so dim that it was detecting it as breaking the IR barrier. So....I am new to this, but learning. And I went with the 330ohm resistor on the 5v line as the schematic shows. By my calculations (again, i could be wrong!) that is way too much resistance. The tech sheet on the LED says it has 1.6voltage drop (forward voltage) and I think if I'm reading it right, I need to supply 100mah to this LED.  So using ohms law of V = I X R. To get the V...5v - 1.6 = 3.4 . So 3.4 V = 100mah X Resistance. So....3.4 / .1 = 34. So I think I need a 34ohm resistor, rather than 330. Does my math sound right? I also wonder if I should have gotten a different LED. The TSHF6410 is 890nm. And the IR receiver's peak wavelength is 940nm. I can use a TV remote from across the room and the sensor detects it and counts it as a goal, but i just tried a 100 ohm resistor (lowest i currently have) on the IR LED and the sensor still cant detect the LED if its further than maybe 6-8 inches away.

swehner, 2019-11-15:
Hey,

Sure - your calculation seems correct, you'd need a lower resistor to drive the LED at that current.
I think the distance we had between the LED and the receiver was smaller - something around 4-5 inches.
I'll update the resistor values, cause you are right in that they are definitely too high. Not sure if we ended up changing them in or installation and I just failed to update the spec.
Thanks for pointing it out.
Regarding the wavelengths of the IR Led and receiver, I know they don't match exactly, but we didn't find this to be a problem.
What helped us also was to make sure the beam of the led is restricted (e.g. by putting the led in a hole in one of the walls on the ball pickup chute)

masseyjeremy, 2019-11-15:
Excellent! I really appreciate the response. Sounds like I'm on the right track. I have a variety pack of resistors coming in tomorrow, so when they come in I'll experiment and see what I can get to work. My testing has just been on a breadboard, and manually pointing the LED towards the receiver. I havnt actually installed in the table yet....I also have a Tornado, with same layout as yours. Really looking forward to getting this working. I'll send you a pic of the setup when its completed.

masseyjeremy, 2019-11-16:
The resistors came in today. I used a 33ohm, and measured the current going to the LED, and its pretty much exactly 100ma now. But, it did not improve anything. The maximum distance I can have the LED from the IR receiver is about 6 inches. But at that distance it continuously counts goals and does not stop. The only way I can get it to stop is to put the LED about 1 cm from the IR receiver. At that distance if I block the signal, it properly counts goals properly (only when i block the led). And as I mentioned, a TV remote gets picked up from across the room....probably 10 feet or more away. So the IR receiver definitely seems to be working ok. It just doesnt seem to like my LEDs. The only things I can think of: Maybe the 38kHz signal from the Pi is not working properly. I've double checked my wiring to the LED, including trying the transistor the other way around (swapping collector/emitter), but i just cant get this to work right. If you have any ideas, please let me know. I'm not sure what else to try other than buying and trying out different LED's / Receivers. Again, thanks so much for the help and for sharing this code. It will be great when I have it setup

masseyjeremy, 2019-11-16:
So I think i might have found my problem. I noticed this today when I closed the app: "ERROR - /bin/sh: 1: gpio: not found". Maybe this is preventing the 38khz signal to work on GPIO18 pin? I'm not sure how to fix this. I've done:

- pip3 install RPi.GPIO
- pip3 install wiringPi
- pip3 install gpio

But this did not fix it

swehner, 2019-11-17:
Hey! Great to hear that this worked - I'll add gpio to the dependencies in the check script (even though it's for the pi only version it should be good to install it anyways.
There are a few posts on the internet around different problems with gpio from rc.local: https://raspberrypi.stackexchange.com/questions/4664/setting-gpio-value-on-boot

E.g. mentions that it's not on the default path and that you'd have to add the full path.
You can try to run foos from rc.local this way:

`PATH=$PATH:/usr/local/bin sudo -u pi /home/pi/foos/foos.sh`

or export the PATH before

```
export PATH=$PATH:/usr/local/bin
sudo -u pi /home/pi/foos/foos.sh
```

If this doesn't work, I think the easiest would be to add a "set -x" to the rc.local and see if you can get some debug output.

masseyjeremy, 2019-11-18:
So I tried both of these methods of setting the path in the rc.local but it didnt work. I also tried putting the entire path in it (the path that I got when logged in as pi).

But maybe the root of the issue can be fixed through getting the software side of things setup right. Which brings up a new question. I tried connecting a pi camera/ enabled the camera plugin, but when foos booted up, it crashed and said I was missing a module. I installed what it said i was missing (with sudo pip3....seems like it was inotify and one or two other ones) and did this a few times with different modules it said it needed, but in the end i was getting different python errors that were more difficult than just installing a missing component.

This leads me to this question: Is there a build of raspbian lite that you recommend using? I had originally installed the latest of wheezy I think, since I know this code has been around for several years so i figured you may have originally used an older version. I couldnt get python3 to work correctly so i just went to the latest of Jessie. This one worked better, and python3 was working, and i used the "pip3 install -r requirements.txt", but I still had to install a few things manually. I might have this off (not sure I took perfect notes), but I think I had to run these to get things working:

sudo apt-get install libjpeg-dev
sudo apt-get install zlib1g-dev
sudo apt-get install libpng-dev
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
masseyjeremy, 2019-11-18:
Yeah, i ran the check. And it says everything is "OK" except for python deps, where it says: "Can't check python3 deps for the moment". For GPU memory, I gave it 256. I'm going to try to get it working with the nano tonight, and then once done maybe will try switching to stretch to see if things work better there.

masseyjeremy, 2019-11-20:
So, update! I got the Arduino nano hooked up, and goal scoring is now working perfect. In the few games we've played, it was 100% perfect in goal tracking.

So on the side, i tried setting up a new SD card, using the latest build of Stretch this time. I'm basically starting over under stretch and seeing if I can get the camera to work this time. I followed the instructions exactly, including running the check and also running "pip3 install -r requirements.txt". I still had to manually run these two steps in order for Pillow to install since the Pillow install failed and was complaining of missing required dependencies:
sudo apt-get install libjpeg-dev
sudo apt-get install libpng-dev

So then in the config.py, i enabled the standby plugin and io_serial plugin. Then i started up the foos code. But I'm getting this error below. I'll try to troubleshoot later tonight or tomorrow, but any ideas?
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

swehner, 2019-11-20:
Great to hear that the Arduino setup worked! I'll see if I can verify the seup for the pi-only version during the weekend.

Regarding the issue during the monkey_patch function.
This isn't actuallly needed for newer versions of pi3d. Can you try removing/commenting the following line?
https://github.com/swehner/foos/blob/master/foos/ui/ui.py#L301

I think there were some recent changes around the piece of code that I was patching here in the recent 2.34 release that make my horrible paching fail (I shouldn't be patching anyways...)
https://github.com/tipam/pi3d/commit/316d5f65beddb21ed0052a60aecafde20419ecda

If commenting this line doesn't work, I'll suggest downgrading it to pi3d 2.32
There's an issue #70 regarding possible issues on the pi4 that I think were addressed in pi 2.34.
I'll try to double check it this weekend and commit the change to remove the patching function

masseyjeremy, 2019-11-21:
You are awesome! I probably would not have figured that out. Commenting out that line has everything working now. Video playback is working great, except for the FOV. Its good enough that I would be happy enough with it as is, but for the sake of trying to get it better......

As other people have mentioned, I cant get the whole table in view with camera v2. Almost, but not quite. I tried all the different resolution mode settings as you pointed someone else to (https://picamera.readthedocs.io/en/release-1.12/fov.html).
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

Mode 7,1, and 6 were pretty terrible. Modes 2,3,5 actually gave me the same result, which is interesting because 2 and 3 are the full sensor area (see image above) but its at 4:3 ratio. I wonder if the top and bottom bands are getting cut off because its displaying it at 16:9. Do you happen to know how to maybe make it display the 4:3 video, but inside my 16:9 monitor? Understanding that it would have vertical bands on both sides. If I cant figure it out, i may just see if i can find a v1 camera somewhere.

Thanks again for all your help. We're loving this setup!

masseyjeremy, 2019-11-25:
As an update, in the end, v2 of the camera actually had a better field of view. I think the difference was that you have your v1 camera a little further away from the table, whereas mine is closer. Anyway, I cant get the goalies on either side in the camera view, but thats ok. Good enough. Overall we're super happy with the setup. Thank you for all your help in getting this working! And heres a few photos of the completed project. We also installed a red button on the side of the monitor box to turn the pi on and off. And the table plugs into the wall with just a single network cable. All other cables are hidden. You can close this ticket, but I just wanted to give the final update with these pics.  Thanks again!!!
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

swehner, 2019-11-25:
That looks awesome! Thanks for sending in the pictures - I should actually add a gallery with pictures of other builds :D
Good that the camera works out of you, btw: I like the LEGO touch to it :D ... and the fact that you managed to hide all the cables!

Re camera: maybe some of the cheap fisheye attachment for cellphones might work https://www.aliexpress.com/w/wholesale-fisheye-lens.html ? Unfortunately I never got around to trying it...
Thanks again for letting me know how it turned out! Hope you enjoy it!

Closed 2019-11-25.

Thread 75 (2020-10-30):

Problem to install libav-tools

timomanson, 2020-10-30:
Hi ,

bitte schau dir das bild an , dann siehst du mein problem !

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

swehner, 2020-10-31:
Hi Timo,

Hast du den letzten code? (Ich habe seit Nov 2019 auf ffmeg umgeschalten d278b97fe82478c9edd7a422d6b53e2820c81f16
Ich versuche gerade es auf einer RaspberryPi mit buster laufen zu lassen und habe kein Problem damit

```
pi@raspberrypi:~/foos $ lsb_release -a
No LSB modules are available.
Distributor ID:	Raspbian
Description:	Raspbian GNU/Linux 10 (buster)
Release:	10
Codename:	buster
```
Habe gerade auch einen fix für das Problem mit libpng hochgeladen 629a69438dce79e22bb0f31e9558de9f4e77cf47
Hoffentlich läufts damit!

timomanson, 2020-11-01:
Hi, das Problem ist scheinbar gelöst.
Jetzt ist folgendes.
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

timomanson, 2020-11-01:
Der Player wird nicht gefunden

swehner, 2020-11-01:
Du musst den Befehl der in blau geschrieben ist ausführen: "pushd
video/player; ..."
Wahrscheinlich bekommst du einen weiteren fehler weil ilclient nicht
gefunden wird - auch hier wird ein Befehl angezeigt um das zu kompilieren

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

timomanson, 2020-11-02:
alles klar - alles grün
wenn ich im menue ein spielmodus bis 10 haben möchte - ist das kompliziert hinzuzufügen ?

swehner, 2020-11-02:
Kopier diese zeile in dein config.py und ändere sie wie du willst: https://github.com/swehner/foos/blob/629a69438dce79e22bb0f31e9558de9f4e77cf47/config_base.py#L25

timomanson, 2020-11-03:
alles klar funktioniert.
Tut mir leid wenn ich dir so auf die nerven falle , aber ich habe weitere probleme.

Wenn ich jetzt ein neues spiel beginne, sollten dann nicht beide auf 0:0 SPRINGEN ?

Bei mir ist es , das der spielstand bei abbruch, stehen bleibt.

Meine Lichtschranke funktioniert nicht.

Ist wie folgt angeschlossen (ohne arduino)

IR 2
Vcc an    5V
GND an GND
DATA an GPIO 14  (PIN 8) ---- in eurer zeichnung ist der mittlere anschluss der IRs der data anschluss eigentlich ist dieser
                                                 Left = Data
                                                 MID = GND
                                               Right = vcc
IR LED 2:

+LED an   R2 330 Ohm an   5V
- LED an transistor ( Collector)

Die LED leuchtet allerdings nicht.

Kannst du mir sagen wie man die Funktion testen kann ?

timomanson, 2020-11-03:
Ich habe das PI Modell 3B

timomanson, 2020-11-03:
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

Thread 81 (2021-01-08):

IR Lichtschranke

timomanson, 2021-01-08:
Hi, ich habe mal wieder ein Problem. Nachdem wir alles in den Tisch eingebaut hatten, lief die ir Schranke nicht mehr. Die zählte von Anfang bis Ende durch, ohne das ein Ball im Spiel war.
Wir haben die Sensoren direkt im Tor verbaut. Woran könnte es liegen?

Mfg

Timo 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

swehner, 2021-01-10:
Hi Timo,

Wenn sie einfach so durch zählt liegts vielleicht an einem Problem vom Kabel. Kann's sein dass da ein Wackelkontakt ist?
Wie sind die Kabel verbunden? Ich nehme an, der andere Sensor funktioniert gut - und ist der gleich eingebaut?

timomanson, 2021-01-31:
Hi, also das durchzählen ist wegen nem Kabel gewesen.
Wie bekomme ich jetzt die sensoren empfindlicher eingestellt, die Tore werden oft nicht gezählt.

Ach ja - und die stoppuhr würde ich gerne verbannen....

MFG

swehner, 2021-02-04:
Hi Timo,

Wir hatten folgende Probleme mit der Lichtschranke: sie war unter dem tisch angebracht und das holz war weiss lackiert. Das hat anscheinend recht viel licht um de ball herum reflektiert - schwarzes klebeband am boden und der decke hat da geholfen.
Was auch hilft ist den Strahl des Leds etwas zu reduzieren - zum beispiel eine schwarzen kurzen strohhalm drüber stecken.

Hoffentlich hilfts was!

timomanson, 2021-02-04:
Alles klar DankeMfgVon meinem Huawei-Telefon gesendet-------- Ursprüngliche Nachricht --------Von: swehner <notifications@github.com>Datum: Do., 4. Feb. 2021, 22:19An: swehner/foos <foos@noreply.github.com>Cc: timomanson <timo-methling@gmx.de>, Author <author@noreply.github.com>Betreff: Re: [swehner/foos] IR Lichtschranke  (#81)

Hi Timo,

Wir hatten folgende Probleme mit der Lichtschranke: sie war unter dem tisch angebracht und das holz war weiss lackiert. Das hat anscheinend recht viel licht um de ball herum reflektiert - schwarzes klebeband am boden und der decke hat da geholfen.

Was auch hilft ist den Strahl des Leds etwas zu reduzieren - zum beispiel eine schwarzen kurzen strohhalm drüber stecken.

Hoffentlich hilfts was!

—You are receiving this because you authored the thread.Reply to this email directly, view it on GitHub, or unsubscribe.

timomanson, 2021-02-10:
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

Hi, also die langsamen Bälle werden gezählt , aber die schnellen Bälle nicht.
Kann man die Unterbrechungszeit programmieren ? Oder andere Sender / Empfänger versuchen ?

Mfg

swehner, 2021-02-10:
Du benutzt die RaspberryPi version, oder? DIe benutzt edge_detection um ein
Tor zu registrieren, Sollte also auch für sehr kurze unterbrechungen
funktionieren (
https://raspberrypi.stackexchange.com/questions/92940/minimum-pulse-width-for-asynchronous-interrupt
)
Ist mir also nicht klar warum das nicht funktionieren sollte.
Passiert das nur bei schnellen Bällen (egal ob sie näher am
Empfänger/Sender sind?)
Ändert sich etwas wenn Empfänger/Sender etwas abgeschirmt sind? Kann es
z.B. sein das sehr schnelle bälle nicht auf dem tisch rollen, sonder etwas
fliegen und Licht durchlassen?

Wir hatten nie Probleme damit - bei uns war aber die Lichtschranke unter
dem Tisch. D.h. die meisten Bälle kamen langsamer durch und sind immer
durch die Schranke gerollt.
Wir hatten die Arduino version, die benutzt polling und nicht edge
detection also hätte ich da mehr probleme erwartet.
Hast du vielleicht die Möglichkeit die Schranke an einem anderen Platz
anzubringen?

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

timomanson, 2021-02-11:
Hi, Also es liegt tatsächlich an der Geschwindigkeit. Rollt der Ball langsam durch wird's gezählt, und schon bei mittlerer Geschwindigkeit zählt er nicht . Kann man da Software technisch noch was ändern oder andere Empfänger besorgen ?MfgVon meinem Huawei-Telefon gesendet-------- Ursprüngliche Nachricht --------Von: swehner <notifications@github.com>Datum: Mi., 10. Feb. 2021, 23:24An: swehner/foos <foos@noreply.github.com>Cc: timomanson <timo-methling@gmx.de>, Author <author@noreply.github.com>Betreff: Re: [swehner/foos] IR Lichtschranke  (#81)

Du benutzt die RaspberryPi version, oder? DIe benutzt edge_detection um ein

Tor zu registrieren, Sollte also auch für sehr kurze unterbrechungen

funktionieren (

https://raspberrypi.stackexchange.com/questions/92940/minimum-pulse-width-for-asynchronous-interrupt

)

Ist mir also nicht klar warum das nicht funktionieren sollte.

Passiert das nur bei schnellen Bällen (egal ob sie näher am

Empfänger/Sender sind?)

Ändert sich etwas wenn Empfänger/Sender etwas abgeschirmt sind? Kann es

z.B. sein das sehr schnelle bälle nicht auf dem tisch rollen, sonder etwas

fliegen und Licht durchlassen?

Wir hatten nie Probleme damit - bei uns war aber die Lichtschranke unter

dem Tisch. D.h. die meisten Bälle kamen langsamer durch und sind immer

durch die Schranke gerollt.

Wir hatten die Arduino version, die benutzt polling und nicht edge

detection also hätte ich da mehr probleme erwartet.

Hast du vielleicht die Möglichkeit die Schranke an einem anderen Platz

anzubringen?

On Wed, Feb 10, 2021 at 5:28 PM timomanson <notifications@github.com> wrote:

> Hi Timo,

>

> Wir hatten folgende Probleme mit der Lichtschranke: sie war unter dem

> tisch angebracht und das holz war weiss lackiert. Das hat anscheinend recht

> viel licht um de ball herum reflektiert - schwarzes klebeband am boden und

> der decke hat da geholfen.

> Was auch hilft ist den Strahl des Leds etwas zu reduzieren - zum beispiel

> eine schwarzen kurzen strohhalm drüber stecken.

>

> Hoffentlich hilfts was!

>

> Hi, also die langsamen Bälle werden gezählt , aber die schnellen Bälle

> nicht.

> Kann man die Unterbrechungszeit programmieren ? Oder andere Sender /

> Empfänger versuchen ?

>

> Mfg

>

> —

> You are receiving this because you commented.

> Reply to this email directly, view it on GitHub

> <https://github.com/swehner/foos/issues/81#issuecomment-776834557>, or

> unsubscribe

> <https://github.com/notifications/unsubscribe-auth/AACCWVC6G7HGQJABSL7XCCTS6KXZ5ANCNFSM4V22TQ6A>

> .

>

—You are receiving this because you authored the thread.Reply to this email directly, view it on GitHub, or unsubscribe.

timomanson, 2021-02-12:
Hi,
wenn ich statt der IR Lichtschranke eine ggf. zwei Lichtschranken =Laser wie diese [hier](https://www.amazon.de/WayinTop-Laserdiode-Lasermodul-Fotowiderstand-Widerstand/dp/B07PHFSR2B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
)
Einsetze - ist es sehr aufwendig das umzuprogrammieren ?
Laser sind unempfindlich von Umgebungslicht, und präziser bei Unterbrechungen ....

MFG

Timo

swehner, 2021-02-14:
Hi,

Also an sich sollte das schon ohne Probleme gehen, mit so einem ähnlichen Schaltkreis wäre das denke ich ohne grosse Veränderungen möglich: https://peppe8o.com/using-photoresistor-from-raspberry-pi-to-detect-light/
Nach dem Link den du mir geschickt reagiert der Fotowiderstand am besten auf grünes Licht 540nm - also denke ich, dass da noch mehr Probleme mit Umgebungslicht auftreten können.
Ich weiss auch nicht wie gut die Ansprechzeit bei diesen Widerständen ist... wenn die recht lange brauchen um den Widerstand zu verändern wenn mehr oder weniger Licht eintritt, dann würde das hier auch nicht viel helfen :(

Bei der Infrarotsperre ist das Signal moduliert - d.h. es sollte weniger empfindlich auf Umgebungslicht von anderen IR-Quellen sein (ausser wahrscheinlich eine Fernsteuerung die normalerweise auch auf 38khz funktionieren)...
Ich habe mal versucht vom Datasheet https://www.vishay.com/docs/82479/tssp58038.pdf mit dem Testsignal zu berechnen wie schnell der Ball rollen kann - bei einer BallGrösse von 3cm, und einer Unterbrechung von 600us, käme das auf 180km/h.
Wenn die Schranke also ordentlich in der Mitte des Balls ist, sollte es denke ich von dem IR Empfänger her funktionieren.

timomanson, 2021-02-14:
Hi, Ich hab einfach Mal die Empfänger getauscht, und siehe da, es läuft wunderbar, er zählt alles....Du hattest mir Mal die config.py von deinem System geschickt, könntest du mir die nochmal zuschicken, hab die Mail versehentlich gelöscht.Jetzt wäre nur noch schön wenn bei Start von foos der Zähler auf 0 steht, ebenfalls wenn man die Modis wechselt. Bekommt man das hin ?MfgTimoVon meinem Huawei-Telefon gesendet-------- Ursprüngliche Nachricht --------Von: swehner <notifications@github.com>Datum: So., 14. Feb. 2021, 20:59An: swehner/foos <foos@noreply.github.com>Cc: timomanson <timo-methling@gmx.de>, Author <author@noreply.github.com>Betreff: Re: [swehner/foos] IR Lichtschranke  (#81)

Hi,

Also an sich sollte das schon ohne Probleme gehen, mit so einem ähnlichen Schaltkreis wäre das denke ich ohne grosse Veränderungen möglich: https://peppe8o.com/using-photoresistor-from-raspberry-pi-to-detect-light/

Nach dem Link den du mir geschickt reagiert der Fotowiderstand am besten auf grünes Licht 540nm - also denke ich, dass da noch mehr Probleme mit Umgebungslicht auftreten können.

Ich weiss auch nicht wie gut die Ansprechzeit bei diesen Widerständen ist... wenn die recht lange brauchen um den Widerstand zu verändern wenn mehr oder weniger Licht eintritt, dann würde das hier auch nicht viel helfen :(

Bei der Infrarotsperre ist das Signal moduliert - d.h. es sollte weniger empfindlich auf Umgebungslicht von anderen IR-Quellen sein (ausser wahrscheinlich eine Fernsteuerung die normalerweise auch auf 38khz funktionieren)...

Ich habe mal versucht vom Datasheet https://www.vishay.com/docs/82479/tssp58038.pdf mit dem Testsignal zu berechnen wie schnell der Ball rollen kann - bei einer BallGrösse von 3cm, und einer Unterbrechung von 600us, käme das auf 180km/h.

Wenn die Schranke also ordentlich in der Mitte des Balls ist, sollte es denke ich von dem IR Empfänger her funktionieren.

—You are receiving this because you authored the thread.Reply to this email directly, view it on GitHub, or unsubscribe.

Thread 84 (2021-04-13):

Problem mit der GUI (RPi only Setup)

dpgoerlich, 2021-04-13:
ich habe leider ein Problem mit dem Starten der GUI deines Instant Replay System. Ich benutze einen Raspberry 2. Die GUI kommt beim Start des Raspberry kurz und ist dann wieder weg. Ich benutze die Variante ohne Arduino. Beim Manuell starten kommt folgender Fehler:

   INFO - Foos v20160814 starting
   INFO - Blank console
   INFO - Display 640x480@25
glGetError 0x500
   INFO - Loading plugins {'league', 'control', 'io_evdev_keyboard', 'score', 'io_debug', 'game', 'sound', 'leds', 'replay', 'io_raspberry', 'menu', 'camera'}
WARNING - Can't find any keyboards to read from - maybe you need permissions
Traceback (most recent call last):
  File "foos.py", line 50, in <module>
    PluginHandler(bus)
  File "/home/pi/workspaces/foos/foos/plugin_handler.py", line 16, in __init__
    self.load(bus)
  File "/home/pi/workspaces/foos/foos/plugin_handler.py", line 24, in load
    p = module.Plugin(bus)
  File "/home/pi/workspaces/foos/plugins/io_raspberry.py", line 91, in __init__
    self.goal_detector_black = GoalDetector(bus, self.goal_pin_black, "black")
  File "/home/pi/workspaces/foos/plugins/io_raspberry.py", line 47, in __init__
    GPIO.add_event_detect(self.pin, GPIO.FALLING, callback=self.on_goal, bouncetime=10)
RuntimeError: Failed to add edge detection

Hat jemand eine Idee woran das liegen kann ?

LG

timomanson, 2021-04-27:
Hi ,

sieht für mich danach aus als hättest du entweder die GPIO´s nicht an oder evtl. im Konfigurations menue den Eindrahtbus eingeschaltet ….

Wäre meine Idee hatte nen ähnlichen Fehler -

Welches Betriebssystem nutzt du ?

Hast du die  WiringPi aufgespielt ?

MFG

Timo

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

dpgoerlich, 2021-04-27:
Hi,

ich hab die GPIO Eingabe der Lichtschranken vorher per Script getestet. Da kommt definitiv das Signal an. Wo konfiguriere ich den Eindrahtbus? Kann aber eigentlich nicht sein, wenn mit simplen Script die Eingabe korrekt funktioniert oder ?

Wiringpi ist installiert.

Betriebssystem ist Standard Raspbian Buster in der aktuellen Version.

LG

dpgoerlich, 2021-04-29:
Hab mal eine neue Speicherkarte zur Hand genommen und es neu aufgesetzt, jetzt läuft es.

Closed 2021-04-29.

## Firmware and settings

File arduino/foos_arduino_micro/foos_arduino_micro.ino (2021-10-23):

#include <TimerOne.h>
#include <stdio.h>

//check buttons every X ms
#define BTN_INTERVAL 10
// Send Pings 'P' every X ms
#define PING_INTERVAL 5000

#define TEST_LED_BLACK A0
#define TEST_LED_YELLOW A2

const char* btnEvents[5][2] = {{"YD_U", "YD_D"}, {"YI_U", "YI_D"}, {"BD_U", "BD_D"}, {"BI_U", "BI_D"}, {"OK_U", "OK_D"}};
#define GOAL_BLACK_STR "BG %lu %lu"
#define GOAL_YELLOW_STR "YG %lu %lu"

#define PIN_GOAL_YELLOW 10
#define PIN_MASK_YELLOW 0b00000001
#define PIN_GOAL_BLACK 11
#define PIN_MASK_BLACK 0b00000010

//input button mask (2-6) - CANNOT use PORTD on Micro
#define BTN_MASK   0b00011111
// On micro A0 = D 18
#define D_BTN_A0   18
// 2= YD, 3=YI, 4=BD, 5=BI, 6=OK
#define D2 2
#define D3 3
#define D4 4
#define D5 5
#define D6 6

void setup() {
	// set analog leds as output
	pinMode(A0, OUTPUT);
	pinMode(A1, OUTPUT);
	pinMode(A2, OUTPUT);
	pinMode(A3, OUTPUT);
	pinMode(A4, OUTPUT);
  // set button modes as input
  pinMode(D2, INPUT_PULLUP);
  pinMode(D3, INPUT_PULLUP);
  pinMode(D4, INPUT_PULLUP);
  pinMode(D5, INPUT_PULLUP);
  pinMode(D6, INPUT_PULLUP);

  //set pin for goals as input
  pinMode(PIN_GOAL_BLACK, INPUT);
  pinMode(PIN_GOAL_YELLOW, INPUT);

  // setup signal for IR Led
  Timer1.initialize(26);  // 26 us = 38 kHz
  // 50% DUTY CYCLE
  Timer1.pwm(9, 512);

  // setup serial
  Serial.begin(115200);
}

//button processing
inline void checkButton(byte changed, byte state, byte idx) {
  if (changed & _BV(idx)) {
    Serial.println(btnEvents[idx][((state & _BV(idx)) != 0)]);
  }
}

inline void disableLeds(){
	for(int x=0;x<5;x++) {
		digitalWrite( (D_BTN_A0 + x), LOW);
	}
}

/*
 * Read the button values and convert to binary mask.
 */
inline byte getButtonState() {
  byte state = 0;
  for (int i=0; i<5; i++) {
    if (digitalRead(D2+i) == LOW) {
      state = state + (1 << i);
    }
  }
  return state;
}

inline byte getGoalState() {
  byte state = 0;
  for (int i=0; i<2; i++) {
    if (digitalRead(PIN_GOAL_YELLOW + i) == HIGH) {
      state = state + (1 << i);
    }
  }
  return state;
}

// check for pressed buttons
byte prevBtns = BTN_MASK;
void processButtons() {
  byte state = getButtonState();
  byte changed = prevBtns ^ (state & BTN_MASK);

  if (changed) {
    // save new state
    prevBtns = state;
    // check which button has changed
    for (byte idx=0; idx < 5; idx++) {
      checkButton(changed, state, idx);
    }
  }
}

unsigned long nextBtnCheck = 0;
unsigned long nextPing = 0;

byte testMode = 0;
// read from serial port and set led status
void processInstructions() {
  if (Serial.available()) {
    int data = Serial.read();
    // from A -> '`' inclusive 5 bits for LEDS - turns into 0 ->31 (for bits B00011111)
    if (data >= 'A' && data <= ('A' + 32)) {
      // take printables ASCII character and shift down
      data = (data & 0xFF) - 'A';
      for(int x=0;x<5;x++) {
        int p = 1 << x;
        if (data & p) {
          // 18 = A0, 19 = A1, etc
          digitalWrite( (D_BTN_A0 + x), HIGH);
        } else {
          digitalWrite( (D_BTN_A0 + x), LOW);
        }
      }
    } else  if (data == 't') {
      testMode = 1;
      //disable all leds
      disableLeds();
      Serial.println("TEST_MODE");
    } else if (data == 'u') {
			testMode = 0;
			//disable all leds
			disableLeds();
			Serial.println("NORM_MODE");
    }
  }
}

inline void processGoal(byte mask, bool *goal, unsigned long *goalTime, unsigned long *offTime, const char *goalString) {
  byte state = getGoalState();
  static char l[100];
  if ((state & mask) > 0) {
    if (!*goal) {
      *goal = true;
      *goalTime = micros();
    }
  } else {
    if (*goal) {
      unsigned long now = micros();
      *goal = false;
      sprintf(l, goalString, now - *goalTime, *goalTime - *offTime);
      Serial.println(l);
      *offTime = now;
    }
  }
}

unsigned long goalTimeY = 0;
unsigned long goalTimeB = 0;
unsigned long offTimeY = 0;
unsigned long offTimeB = 0;
bool goalY = false;
bool goalB = false;
unsigned long start = 0;
byte prev_goals = 0;
#define TIME_ELAPSED(now, ts) ((long)(now - ts) >= 0)
bool goalsEnabled = false;
// enable goals a bit after startup to avoid false events
unsigned long reenableGoalsAt = 1000;


void loop() {
  if (testMode) {
    digitalWrite(TEST_LED_BLACK, digitalRead(PIN_GOAL_BLACK));
    digitalWrite(TEST_LED_YELLOW, digitalRead(PIN_GOAL_YELLOW));
  } else {
    bool processingGoal = 0;
    if (goalsEnabled) {
      processGoal(PIN_MASK_YELLOW, &goalY, &goalTimeY, &offTimeY, GOAL_YELLOW_STR);
      processGoal(PIN_MASK_BLACK,  &goalB, &goalTimeB, &offTimeB, GOAL_BLACK_STR);
    }
    // don't process buttons or instructions during goal checking
    if (goalY | goalB) {
      return;
    }

    unsigned long now = millis();
    if (goalsEnabled == 0 && TIME_ELAPSED(now, reenableGoalsAt)) {
      goalsEnabled = 1;
      reenableGoalsAt = 0;
    }

    if (TIME_ELAPSED(now, nextBtnCheck)) {
      nextBtnCheck = now + BTN_INTERVAL;
      processButtons();
    }
    if (TIME_ELAPSED(now, nextPing)) {
      nextPing = now + PING_INTERVAL;
      Serial.println("P");
    }
  }
	processInstructions();
  delay(1);
}

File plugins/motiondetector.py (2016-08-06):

import time
import os
from inotify_simple import INotify, flags
import numpy as np
import multiprocessing as mp
import logging

import foos.config as config

logger = logging.getLogger(__name__)


class EventGen:
    """Receive movement status from detector, dedup and send events.
    Sends 'movement_detected' at most every 2 second while movement is detected.
    Sends 'people_start_playing' and 'people_stop_playing' (after absence_timeout w/o movement)"""
    def __init__(self, bus, absence_timeout, max_interval):
        self.absence_timeout = absence_timeout
        self.last_mv = 0
        self.last_mv_event_time = 0
        self.max_interval = max_interval
        self.movement = None
        self.bus = bus

    def reportMovement(self, newmovement):
        now = time.time()
        if newmovement:
            if now - self.last_mv > self.max_interval:
                self.last_mv = now
                self.bus.notify("movement_detected")
        else:
            if now - self.last_mv < self.absence_timeout:
                # wait a bit before assuming people have left
                return

        if self.movement != newmovement:
            event = "people_start_playing" if newmovement else "people_stop_playing"
            logger.info(event)
            self.bus.notify(event)
            self.movement = newmovement


class MotionDetector:
    """Detect motion in a frame"""
    def __init__(self, size, vector_threshold, min_vectors, crop_x, min_frames_movement):
        self.size = size
        self.frame_size_bytes = self.size[0] * self.size[1] * 4
        self.vector_threshold = vector_threshold
        self.min_vectors = min_vectors
        self.min_frames_movement = min_frames_movement
        self.crop_x = crop_x

    def frame_has_movement(self, frame):
        arr = np.fromstring(frame, np.dtype("2<u2"))
        arr = arr[:, 1].astype('float')
        arr = np.reshape(arr, (self.size[1], self.size[0]))
        arr = arr[:, self.crop_x:-self.crop_x]
        arr = np.square(arr)
        mvs = len(arr[arr > self.vector_threshold])
        has_movement = (mvs > self.min_vectors)
        return has_movement

    def runs(self, l):
        runs = []
        if len(l) == 0:
            return []

        prev = l[0]
        n = 1
        for i in l[1:]:
            if prev == i:
                n += 1
            else:
                runs.append((prev, n))
                n = 1

            prev = i

        runs.append((prev, n))
        return runs

    def readFrame(self, f):
        d = f.read(self.frame_size_bytes)
        ld = len(d)
        if ld == 0:
            return None
        
        if ld != self.frame_size_bytes:
            logger.warning("Movement vector file size is off - expected a full frame of %d bytes (=%d * %d * 4) but got %d" % (self.frame_size_bytes, self.size[0], self.size[1], ld))
            logger.warning("This probably means that md_size is misconfigured")
            return None
        
        return d

    def chunk_has_movement(self, d):        
        # Skip first frame
        frame = self.readFrame(d)
        movement_in_frame = []
        while True:
            frame = self.readFrame(d)
            if frame is None:
                break

            movement_in_frame.append(self.frame_has_movement(frame))

        logger.debug("Frame %s", "".join(map(lambda x: 'M' if x else '.', movement_in_frame)))
        # get runs of contiguous frames with or without movement
        rs = self.runs(movement_in_frame)
        # append a default value in case there are no frames with movement
        rs.append((True, 0))
        # get the longest run of frames with movement
        streak = max([r[1] for r in rs if r[0]])
        mv = streak >= self.min_frames_movement
        logger.debug("Detected movement: %6s %d/%d", mv, streak, self.min_frames_movement)
        return mv


class Plugin:
    def __init__(self, bus):
        self.md = MotionDetector(config.md_size, config.md_mv_threshold,
                                 config.md_min_vectors, config.md_crop_x, config.md_min_frames)
        self.eg = EventGen(bus, config.md_ev_absence_timeout, config.md_ev_interval)
        self.watch_dir = os.path.join(config.replay_path, 'fragments')
        self.prefix = 'mv'
        mp.Process(daemon=True, target=self.run).start()

    def run(self):
        while not os.path.exists(self.watch_dir):
            logger.info("Waiting for %s...", self.watch_dir)
            time.sleep(30)

        inotify = INotify()
        watch_flags = flags.CLOSE_WRITE
        logger.info("Watching %s", self.watch_dir)
        try:
            inotify.add_watch(self.watch_dir, watch_flags)

            # And see the corresponding events:
            while True:
                events = inotify.read()
                matching = [f.name for f in events if f.name.startswith(self.prefix)]
                if len(matching) > 0:
                    # take only the last file
                    self.processForMovement(os.path.join(self.watch_dir, matching[-1]))

            inotify.close()
        except:
            logger.exception("Error when setting up inotify")

    def processFile(self, f):
        with open(f, 'rb') as d:
            return self.md.chunk_has_movement(d)

    def processForMovement(self, filename):
        has_movement = self.processFile(filename)
        self.eg.reportMovement(has_movement)

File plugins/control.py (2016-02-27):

from .buttons import *


class Plugin(Buttons):
    def __init__(self, bus):
        super().__init__(bus, long_press_delay=0.6)

    def generateKeyMap(self):
        key_map = {}
        for d in [up(['black_minus'], ('decrement_score', {'team': 'black'})),
                  up(['black_plus'], ('increment_score', {'team': 'black'})),
                  up(['yellow_minus'], ('decrement_score', {'team': 'yellow'})),
                  up(['yellow_plus'], ('increment_score', {'team': 'yellow'})),
                  up(['ok'], ('replay_request', {}), long=('upload_request', {})),
                  down(['ok'], ('button_will_replay', {}), long=('button_will_upload', {})),
                  up(['black_minus', 'black_plus'], ('reset_score', {}), long=None),
                  up(['yellow_minus', 'yellow_plus'], ('reset_score', {}), long=None),
                  down(['black_minus', 'black_plus'], None, long=('menu_show', {})),
                  down(['yellow_minus', 'yellow_plus'], None, long=('menu_show', {}))]:
            key_map.update(d)
        return key_map

    def process_event(self, ev):
        if ev.name == 'menu_visible':
            self.setEnabled(False)
        elif ev.name == 'menu_hidden':
            self.setEnabled(True)
        else:
            super().process_event(ev)

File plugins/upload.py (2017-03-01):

#!/usr/bin/env python
import http.client
import httplib2
import os
import random
import sys
import time
import logging
from foos.process import call_and_log
import foos.config as config
from apiclient.discovery import build
from apiclient.errors import HttpError
from apiclient.http import MediaFileUpload
from oauth2client.client import flow_from_clientsecrets
from oauth2client.file import Storage
from oauth2client.tools import argparser, run_flow

logger = logging.getLogger(__name__)

# Explicitly tell the underlying HTTP transport library not to retry, since
# we are handling retry logic ourselves.
httplib2.RETRIES = 1

# Maximum number of times to retry before giving up.
MAX_RETRIES = 10

# Always retry when these exceptions are raised.
RETRIABLE_EXCEPTIONS = (httplib2.HttpLib2Error, IOError, http.client.NotConnected,
                        http.client.IncompleteRead, http.client.ImproperConnectionState,
                        http.client.CannotSendRequest, http.client.CannotSendHeader,
                        http.client.ResponseNotReady, http.client.BadStatusLine)

# Always retry when an apiclient.errors.HttpError with one of these status
# codes is raised.
RETRIABLE_STATUS_CODES = [500, 502, 503, 504]

CLIENT_SECRETS_FILE = "client_secrets.json"


def get_authenticated_service():
    upload_scope = 'https://www.googleapis.com/auth/youtube.upload'
    flow = flow_from_clientsecrets(CLIENT_SECRETS_FILE, scope=upload_scope)
    storage = Storage("%s-oauth2.json" % sys.argv[0])
    credentials = storage.get()

    if credentials is None or credentials.invalid:
        flags = argparser.parse_args(args=['--noauth_local_webserver'])
        credentials = run_flow(flow, storage, flags)

    return build('youtube', 'v3', http=credentials.authorize(httplib2.Http()), cache_discovery=False)


def initialize_upload(title=None, file='/tmp/replay/replay_long.mp4'):
    youtube = get_authenticated_service()
    if not title:
        title = 'Tuenti foos replay'
    body = {
        'snippet': {
            'title': title,
            'description': title,
        }
    }

    # Call the API's videos.insert method to create and upload the video.
    insert_request = youtube.videos().insert(
        part=",".join(list(body.keys())),
        body=body,
        # The chunksize parameter specifies the size of each chunk of data, in
        # bytes, that will be uploaded at a time. Set a higher value for
        # reliable connections as fewer chunks lead to faster uploads. Set a lower
        # value for better recovery on less reliable connections.
        media_body=MediaFileUpload(file, chunksize=-1, resumable=True))

    return resumable_upload(insert_request)


# This method implements an exponential backoff strategy to resume a
# failed upload.
def resumable_upload(insert_request):
    response = None
    error = None
    retry = 0
    while response is None:
        try:
            status, response = insert_request.next_chunk()
            if 'id' in response:
                logger.info("Video id '%s' was successfully uploaded.", response['id'])
                return response['id']
            else:
                logger.error("The upload failed with an unexpected response: %s", response)
                return False
        except HttpError as e:
            if e.resp.status in RETRIABLE_STATUS_CODES:
                error = "A retriable HTTP error %d occurred:\n%s" % (e.resp.status, e.content)
            else:
                raise
        except RETRIABLE_EXCEPTIONS as e:
            error = "A retriable error occurred: %s" % e

        if error is not None:
            logger.error(error)
            retry += 1
            if retry > MAX_RETRIES:
                logger.error("No longer attempting to retry.")

            max_sleep = 2 ** retry
            sleep_seconds = random.random() * max_sleep
            logger.error("Sleeping %f seconds and then retrying...", sleep_seconds)
            time.sleep(sleep_seconds)


class Plugin:
    def __init__(self, bus):
        self.bus = bus
        self.bus.subscribe(self.process_event, thread=True)
        self.replay_data = {}
        self.current_score = ('?', '?')

    def process_event(self, ev):
        if ev.name == 'score_changed':
            self.current_score = ev.data['yellow'], ev.data['black']
        elif ev.name == 'replay_start':
            self.replay_data = ev.data

        if ev.name != 'upload_request':
            return

        self.bus.notify('upload_start')
        text = 'Replay'
        if self.replay_data.get('type') == 'goal':
            text = '{} goal'.format(self.replay_data.get('team', '?').capitalize())

        title = "{}: {}-{}".format(text, self.current_score[0], self.current_score[1])
        logger.info("Uploading video: %s", title)

        try:
            in_file = os.path.join(config.replay_path, 'replay_long.h264')
            out_file = os.path.join(config.replay_path, 'replay_long.mp4')
            call_and_log(["video/convert.sh", in_file, out_file])
            video_id = initialize_upload(title, out_file)
            url = 'http://www.youtube.com/watch?v={}'.format(video_id)
            self.bus.notify('upload_ok', url)
            return
        except HttpError as e:
            logger.error("An HTTP error %d occurred:\n%s", e.resp.status, e.content)
        except Exception as e:
            logger.error("An error occurred: %s", e)

        self.bus.notify('upload_error')

if __name__ == '__main__':
    file = sys.argv[1]
    if not os.path.exists(file):
        logger.error('File not found %s', file)

    title = file
    initialize_upload(title, file)

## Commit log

2015-10-22 Add BG. Add arduino sketch
2015-10-23 Recent changes to the replay and camera scripts
2015-10-23 Add 'n' button to replay latest play
2015-11-28 Some cleaning and improvements
    * Make the code ready to run out of the raspberry
    * Some code cleaning
    * Add new comunication options for the buttons
2015-11-29 Test buttons
2015-12-03 Enable IR Output and check for Sensor input
2015-12-05 Rename & fix some things
    [test_buttons.ino]
2015-12-06 Final improvements to make a working code for raspberry
2015-12-06 Use timerOne and interrupts
2015-12-06 Move buttons around
2015-12-06 Disable Leds when switching off test mode
2015-12-09 Switch sides
2015-12-09 Redraw the full board on any event coming from stdin
2015-12-11 Tests with SDL drivers
2015-12-11 Set driver to fbcon
2015-12-11 Enable X11 driver again so it works on laptops
2015-12-11 Fix wrong methods in abstract class
    [io_base.py]
2015-12-11 Separated the clock to a separate thread generating events
2015-12-12 Fix framerate and add milliseconds
2015-12-13 Switch black/yellow
2015-12-13 Fix missing sleep that was giving performance problems
    [io_keyboard.py]
2015-12-14 Add leds control class (not used yet)
2015-12-14 Fix some problems on the bot
    [hipbot.py]
2015-12-14 Bugfix & config move
    [hipbot.py]
2015-12-14 Fix problem with binaries from serial
    [io_serial.py]
2015-12-15 Add live preview to tu run-camera.sh
2015-12-15 Add sample led controller
2015-12-15 Add leds
2015-12-15 Fix led order and io_serial writer
    [io_serial.py]
2015-12-15 Refactor Led I/O
2015-12-16 Switch sides on hipbot messages
2015-12-19 Fix on ledcontroller and deleted old led controller
    [leds.py]
2015-12-27 Optionally draw Leds onscreen. 25 as default FPS
2015-12-27 Led error pattern, change goal
    [io_keyboard.py]
2015-12-27 Use config instead of flag for onscreen leds
2015-12-27 Add LED feedback for long press upload
2015-12-28 Fix youtube uploader to use oauth without local server
    [upload.py]
2015-12-29 Use bus for led events
2015-12-31 Use bus for Buttons->Scoreboard interaction
2015-12-31 Nearly all led controller input from bus
2015-12-31 Camera preview on the left
2016-01-01 Avoid creating extra events due to keyboard autorepeat
    [io_keyboard.py]
2016-01-01 Fix ledcontroller test mode to use the Bus
2016-01-01 Short animation when switching to overlay mode and back
2016-01-02 Move buttoncontroller and ledcontroller to a separate file
2016-01-03 Reorder pin setup and sleep to avoid false goals
    [foos_arduino.ino]
2016-01-04 Fix switched standby/power on commands
    [standby.py]
2016-01-08 Button controller independent thread and button_upload feedback event
2016-01-09 Reorder assignments to avoid bugs
    [io_base.py]
2016-01-20 Add documentation
    [foos_arduino.fzz]
2016-01-27 Refactor buttons, show & hide menu and switch keymaps
2016-02-08 Add sample script for movement detection
2016-02-08 Fix prints and watch_dir
2016-02-08 Motion detector as plugin running as a thread
2016-02-08 Turn TV on when movement is detected, print info
2016-02-09 Make motion detector more resistent to camera movement
2016-02-15 Print league game start
2016-02-15 Print points per player
2016-02-15 Cancel game, radio buttons, font w/circles
2016-02-16 Change radio buttons in font, change in menu
2016-02-17 Filter matches with results, rename config
2016-02-21 Remove prints
2016-02-23 Fix bug show players with 0 points
    [league.py]
2016-02-25 Fix manual replay messages when uploading
    [upload.py]
2016-02-25 Separate goal events from button events
2016-02-27 Some small fixes on several files
    [buttons.py, control.py, game.py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]
2016-02-28 Fix resetting match to None
    [league.py]
2016-02-29 Fix bug with events from serial
    [io_serial.py]
2016-03-01 Mount replay path on a tmpfs, closes #12
2016-03-14 Move replay and camera to plugins
2016-03-14 Reorg button & goal pins
2016-03-14 Add rc to tsop58038
    [foos_arduino.fzz]
2016-03-14 Update schematics
    [foos_arduino.fzz]
2016-03-14 Use sprintf and fix warnings
    [foos_arduino.ino]
2016-03-18 Timeout close sound and fixes
    [game.py, sound.py]
2016-03-18 Display sudden death instead of timer
2016-04-17 Two sample set of plugins - live with everything and dev
2016-06-12 Add filter for short goals
    [arduino.py, score.py]
2016-07-28 Fix missing comma in sample config
2016-07-31 Add evdev keyboard support
    PI user is by default in input group and can read from physical keyboards
    Fixes #22
    [io_evdev_keyboard.py]
2016-08-06 Refactor config to allow overrides
    Sample config will eb in config_base.py
    Overrides can be added to config.py if it exists.
    config.py.sample will now be a sample for the overrides file.
2016-08-20 Separate camera parameters and read them in the script
2016-11-11 Added plugin for IO using Raspberry Pi GPIO pins. See config.py.sample for configuration example. + Image for showing score - 10
2016-11-14 Add doc on disabling the framebuffer to the troubleshooting
2016-11-15 RPi only version does not need to be launched as root: Replaced PWM config based on wiringpi binding with using gpio utility which does run as root (setuid).
    [io_raspberry.py]
2017-01-21 Fixing HW BOM to correct transistor type (should be PNP)
2017-01-28 Adapt to changes in pi3d >v2.15
    Use c_uint for text to avoid TypeError (closes #44)
    Set pi3d logger to WARN to avoid printing out lots of info messages
2019-04-02 Added schematics for RPi only setup
    [foos_RPi_only.fzz]
2019-11-10 Update schematics and BOM to use NPN transistor
    [foos_RPi_only.fzz, foos_arduino.fzz]
2019-11-24 Switch from avconv to ffmpeg
2020-04-10 Adding support for Arduino Micro
2021-10-23 minor fix for loop in micro code
    [foos_arduino.ino, foos_arduino_micro.ino]
2021-10-23 Adding Ard/Micro w/BreakBeam Support
    [foos_RPi_only.fzz, foos_arduino.fzz, foos_arduino_micro.fzz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]
